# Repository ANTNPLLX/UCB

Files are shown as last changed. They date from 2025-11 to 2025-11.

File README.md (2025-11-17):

# USB Cleaner Box






**[User quick guide (EN)](Documents/user_quick_start_en.md)**

**[User quick guide (FR)](Documents/user_quick_start_fr.md)**

An interactive USB security scanning and cleaning system for Raspberry Pi with LCD display, LED indicators, button controls, and audio feedback.

Project created with the help of several LLM tools.

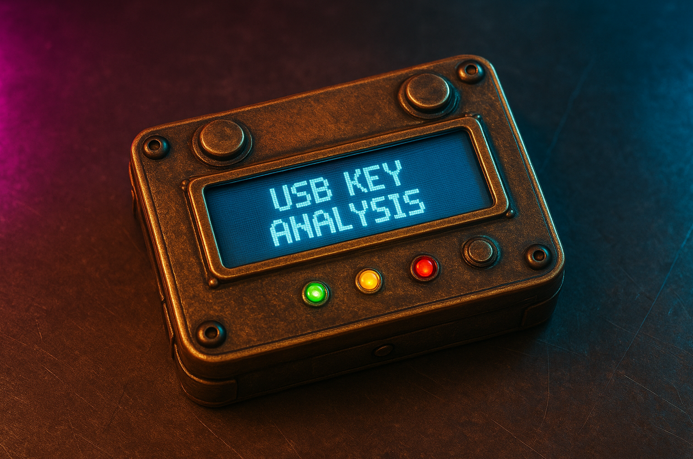
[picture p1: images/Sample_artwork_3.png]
sample_artwork


## Features

- 🔌 **Plug & Play** - Auto-detects USB devices
- 🎛️ **Interactive Interface** - Select Operation (workers) to perform on the USB Drive. 
- 📄 **Logging** - All operations logged
- 🧩 **Extensible** - Add custom workers without modifying code
  
### Built-in Workers : 
- 🔍 **Malware Scanning** - ClamAV virus detection (disabled because clamAV use too much memory for Raspberry PI 3)
- ⚡ **Executables Check** - search scripts, PE or other executable files, even if hidden.
- ❄️ **Vitrification** - Convert Office and PDF document to PDF, neutralize other files
- 🔥 **Secure Formatting** - Format USB drive in FAT32

## Quick Start

```bash
# 1. Clone or download
git clone <repository-url> UCB
cd UCB

# 2. Install dependencies
sudo apt-get update
sudo apt-get install -y python3-rpi.gpio python3-smbus clamav

# 3. Enable I2C
sudo raspi-config
# Interface Options → I2C → Enable

# 4. Make executable
chmod +x *.sh workers/*.sh

# 5. Run
sudo python3 usb_cleaner_box.py
```

## How It Works

1. **Insert USB** - Device auto-detects
2. **Answer Questions** - Use LEFT (NO) / RIGHT (YES) buttons
3. **Review Results** - LED colors show status:
   - 🟢 Green = Safe/Clean
   - 🟠 Orange = Warning/Processing
   - 🔴 Red = Threat/Error
4. **Remove USB** - When prompted "Bye bye!"

## Hardware Requirements

| Component | Specification |
|---|---|
| **Computer** | Raspberry Pi 3/4 or Zero 2 W |
| **Display** | 16x2 I2C LCD (address 0x27) |
| **LEDs** | 3x 5mm (Green, Orange, Red) |
| **Buttons** | 2x Tactile push buttons |
| **Buzzer** | Passive piezo buzzer (5V) |
| **Power** | 9V battery or USB 5V/2A |

**Total Cost**: ~$110-117 (see [Hardware Wiring Guide](Documents/HARDWARE_WIRING.md) for detailed BOM with pricing)

## Documentation

📚 **Complete documentation available in `Documents/` folder:**

| Document | Description |
|---|---|
| **[Installation Guide](Documents/INSTALLATION.md)** | Step-by-step setup instructions, dependencies, systemd service configuration |
| **[User Guide](Documents/USAGE.md)** | How to use the device with ASCII flow diagrams, button controls, and workflows |
| **[Worker Development](Documents/WORKER_GUIDE.md)** | Create custom workers with examples, templates, and best practices |
| **[Hardware Guide](Documents/HARDWARE.md)** | Component specifications, testing procedures, and hardware troubleshooting |
| **[Hardware Wiring](Documents/HARDWARE_WIRING.md)** | Complete wiring diagrams (9V battery & USB powered) with BOM and prices |
| **[FAQ](Documents/FAQ.md)** | 50+ common questions, troubleshooting tips, and detailed answers |

## Worker System

The USB Cleaner Box uses a **dynamic worker system** for extensibility:

- **Workers** are shell scripts in the `workers/` directory
- Each worker = one YES/NO question on the LCD
- Auto-discovered on startup (no code changes needed)
- Can be enabled/disabled individually
- Executed based on user choices
- Results analyzed and displayed automatically

### Built-in Workers

| Order | Question | Description | Requirements |
|---|---|---|---|
| 10 | "Full analysis?" | ClamAV malware scanning | ClamAV |
| 20 | "Executable chk?" | Detect suspicious executables | - |
| 25 | "Vitrification?" | Convert Office docs to PDF, neutralize other files | LibreOffice |
| 30 | "Format USB?" | Secure USB formatting (FAT32) | - |

### Create Custom Workers

```bash
# 1. Copy template
cp workers/TEMPLATE_worker.sh workers/my_worker.sh

# 2. Edit metadata (max 16 chars for question!)
# WORKER_QUESTION=My question?
# WORKER_ORDER=25
# WORKER_ENABLED=true

# 3. Implement logic (receives device name as $1)

# 4. Make executable
chmod +x workers/my_worker.sh

# Done! Auto-discovered on next run
```

### Enable/Disable Workers

To disable a worker without deleting it:

```bash
# Edit the worker file
nano workers/format_usb.sh

# Change WORKER_ENABLED to false
# WORKER_ENABLED=false

# Restart service
sudo systemctl restart usb-cleaner-box.service
```

Disabled workers are skipped - their questions won't appear on the LCD.

See [Worker Development Guide](Documents/WORKER_GUIDE.md) for details and examples.

## Project Structure

```
UCB/
├── usb_cleaner_box.py       # Main application
├── worker_manager.py        # Worker discovery engine
├── lcd_helper.py            # LCD controller
├── led_control.py           # LED management
├── sound_helper.py          # Buzzer/audio
├── button_input.py          # Button handling
├── usb_detection.py         # USB auto-detection
├── start.sh                 # Launcher script
├── workers/                 # Worker scripts
│   ├── analyze_malware.sh
│   ├── analyze_executables.sh
│   ├── format_usb.sh
│   └── TEMPLATE_worker.sh   # Template for new workers
├── Documents/               # Complete documentation
│   ├── INSTALLATION.md
│   ├── USAGE.md
│   ├── WORKER_GUIDE.md
│   ├── HARDWARE.md
│   ├── HARDWARE_WIRING.md
│   ├── FAQ.md
│   └── WORKER_TEMPLATE.sh
└── README.md                # This file
```

## GPIO Pin Assignments

| Component | GPIO (BCM) | Physical Pin |
|---|---|---|
| Green LED | GPIO16 | Pin 36 |
| Orange LED | GPIO20 | Pin 38 |
| Red LED | GPIO21 | Pin 40 |
| Left Button | GPIO23 | Pin 16 |
| Right Button | GPIO24 | Pin 18 |
| Buzzer | GPIO26 | Pin 37 |
| LCD Power | GPIO4 | Pin 7 |
| LCD SDA | GPIO2 | Pin 3 |
| LCD SCL | GPIO3 | Pin 5 |

## Requirements

### Software
- Raspberry Pi OS (Raspbian)
- Python 3.7+
- RPi.GPIO library
- smbus library (I2C)
- ClamAV (for malware scanning worker)
- LibreOffice (for vitrification worker - auto-installs if needed)

### Hardware
- See [Hardware Guide](Documents/HARDWARE.md) or [Hardware Wiring](Documents/HARDWARE_WIRING.md)

## Auto-Start on Boot

Install as systemd service:

```bash
# Edit service file paths
nano usb-cleaner-box.service

# Install
sudo cp usb-cleaner-box.service /etc/systemd/system/
sudo systemctl daemon-reload
sudo systemctl enable usb-cleaner-box.service
sudo systemctl start usb-cleaner-box.service

# Check status
sudo systemctl status usb-cleaner-box.service
```

## Logs

All operations are logged:

```bash
# View logs
sudo tail -f /var/log/usb_malware_scan.log
```

## Troubleshooting

### Quick Fixes

| Problem | Solution |
|---|---|
| LCD blank | Check I2C: `sudo i2cdetect -y 1` |
| USB not detected | Run with sudo |
| LEDs not working | Check polarity and resistors |
| No sound | Verify passive buzzer + transistor driver |
| ClamAV errors | Update: `sudo freshclam` |

See [FAQ](Documents/FAQ.md) for detailed troubleshooting.

## Contributing

Contributions welcome!

- **New workers** - Add functionality
- **Bug fixes** - Improve stability
- **Documentation** - Help others
- **Hardware designs** - Alternative builds
- **Translations** - Make it global

## Safety & Security

⚠️ **Important**:
- Always run with sudo (required for device access)
- Formatting **permanently deletes all data**
- Red LED = Do not use that USB drive!
- Keep virus definitions updated
- Review logs for detailed information

## License

Open source hardware and software. See individual files for specific licenses.

## Support

- 📖 Read the [Documentation](Documents/)
- 🐛 Check [FAQ](Documents/FAQ.md)
- 📝 Review [Logs](#logs)
- 💬 Open an issue (if applicable)

## Acknowledgments

- **ClamAV** - Open-source antivirus engine
- **Raspberry Pi Foundation** - Incredible platform
- **Community** - Contributors and testers

---

**Quick Links:**
- [Installation](Documents/INSTALLATION.md) | [Usage Guide](Documents/USAGE.md) | [Worker Development](Documents/WORKER_GUIDE.md) | [Hardware](Documents/HARDWARE.md) | [Hardware Wiring](Documents/HARDWARE_WIRING.md) | [FAQ](Documents/FAQ.md)

---

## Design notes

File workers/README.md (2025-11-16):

# Workers Directory

This directory contains worker scripts that perform specific tasks on USB drives. Each worker is a shell script that gets auto-discovered and executed based on user choices.

## Built-in Workers

### 1. **analyze_malware.sh** (Order: 10)
**Question:** "Analyse complete?" / "Full analysis?"
**Purpose:** Scans USB drive for malware using ClamAV antivirus engine
**Enabled:** Configurable (default: enabled)

**What it does:**
- Updates ClamAV virus signatures before scanning
- Checks internet connectivity
- Mounts USB drive and counts files
- Performs full virus scan with real-time progress
- Detects infected files and displays results
- Logs all findings to `/var/log/usb_malware_scan.log`

**Requirements:** ClamAV

**Output:**
- 🟢 Green LED: No malware detected
- 🔴 Red LED: Malware/infected files found
- 🟠 Orange LED: Scan errors or warnings

---

### 2. **analyze_executables.sh** (Order: 20)
**Question:** "Executable chk?" / "recherche fichier Executable?"
**Purpose:** Detects potentially dangerous executable files
**Enabled:** Configurable (default: enabled)

**What it does:**
- Scans for Windows executables (.exe, .dll, .bat, .msi, etc.)
- Detects Linux ELF binaries
- Finds script files (.sh, .ps1, .vbs, .js, etc.)
- Uses both file extensions and magic numbers (MZ, ELF headers)
- Displays summary and details of found executables

**Requirements:** None

**Output:**
- 🟢 Green LED: No executable files found
- 🟠 Orange LED: Suspicious executables detected

---

### 3. **file_vitrification.sh** (Order: 25)
**Question:** "Vitrification?"
**Purpose:** Converts Office documents to safe PDFs and neutralizes other files
**Enabled:** Configurable (default: enabled)

**What it does:**
- **Creates quarantine folder:** `FICHIERS_POTENTIELLEMENT_DANGEREUX/`
  - Stores all original files (not deleted!)
  - Preserves directory structure

- **Step 1A:** Vitrifies existing PDF files (removes malicious content)
  - Processes all .pdf files FIRST
  - Removes JavaScript, embedded files, forms, malicious objects
  - Output: `document.pdf` → `document.pdf_vitrified_.pdf`
  - Skips already vitrified PDFs (ending with `_vitrified_.pdf`)
  - Moves original to quarantine folder

- **Step 1B:** Converts Office documents to clean PDF files
  - Formats: .doc, .docx, .xls, .xlsx, .ppt, .pptx, .odt, .ods, .odp, .rtf
  - Output naming: `original.ext_vitrified_.pdf` (preserves original extension)
  - Removes macros and embedded scripts
  - Moves original to quarantine folder

- **Step 2:** Neutralizes other files with `.hold` extension
  - Prevents execution by renaming (e.g., `malware.exe` → `malware.exe.hold`)
  - Preserves safe formats: .txt, .jpg, .png, .mp3, .mp4, etc.

**Requirements:** LibreOffice (auto-installs if needed)

**Output:**
- 🟢 Green LED: Vitrification completed successfully
- Displays conversion and neutralization counts
- Original files preserved in quarantine folder

**Important:** Original potentially dangerous files are NOT deleted - they are moved to the `FICHIERS_POTENTIELLEMENT_DANGEREUX` folder for review

---

### 4. **format_usb.sh** (Order: 30)
**Question:** "Formatage USB?" / "Format USB?"
**Purpose:** Securely formats USB drive to FAT32
**Enabled:** Configurable (default: enabled)

**What it does:**
- **Safety checks:** Prevents formatting system/root disk
- Unmounts all partitions on the device
- Wipes partition table completely
- Creates new MBR partition table
- Creates single FAT32 partition
- Labels USB as "CLEAN_USB"
- Verifies formatting with multiple methods

**Requirements:** None

**Output:**
- 🟢 Green LED: Format successful
- 🔴 Red LED: Format failed or blocked

**⚠️ WARNING:** Formatting permanently deletes ALL data on the USB drive!

---

### 5. **secure_erase.sh** (Order: 40)
**Question:** "Effacage secure?" / "Secure erase?"
**Purpose:** Securely erases USB drive by overwriting with cryptographically random data
**Enabled:** Configurable (default: enabled)

**What it does:**
- **Maximum security:** Overwrites entire drive with random data using `/dev/urandom`
- **Safety checks:** Prevents erasing system/root disk and critical partitions
- **Progress monitoring:** Displays real-time percentage during erase operation
- Unmounts all partitions before erasing
- Calculates estimated time based on device size
- After secure erase: automatically formats to FAT32 with label "CLEAN_USB"

**Technical Details:**
- Uses `dd if=/dev/urandom of=/dev/sdX bs=4M status=progress`
- Estimated speed: ~20 MB/s write speed
- For 64GB USB: approximately 53 minutes
- Makes data forensically unrecoverable

**Requirements:** None

**Output:**
- 🟢 Green LED: Secure erase and format successful
- 🔴 Red LED: Erase failed or blocked
- LCD displays progress: "Effacement... XX%"

**⚠️ CRITICAL WARNING:**
- This operation PERMANENTLY DESTROYS all data on the USB drive
- Data cannot be recovered after secure erase
- Process can take significant time depending on drive size
- Only use when maximum security is required (e.g., sensitive data removal)

---

### 6. **report_printer.sh** (Order: 35)
**Question:** "Copie rapport?"
**Purpose:** Creates a timestamped report file on the USB drive with current session logs
**Enabled:** Configurable (default: enabled)

**Note:** This worker has Order 35 to ensure it runs BEFORE secure erase (Order 40), allowing reports to be saved before drive is wiped

**What it does:**
- Mounts USB drive
- Extracts all logs from the current session (after session banner)
- Creates timestamped report file: `YYYY-MM-DD_HH-MM_rapport_UCB.txt`
  - Example: `2025-11-15_14-30_rapport_UCB.txt`
  - Includes session banner with full device details
  - All worker choices and execution logs
  - Formatted report with headers and sections
- Displays line count and file size
- Unmounts drive after completion

**Session Detection:**
- Primary: Finds last "SESSION START" banner in logs
- Extracts everything from that banner to end of file
- Fallback: Last 30 lines if no session banner found

**Note:** Each report has a unique filename to prevent overwriting previous reports

**Requirements:** None

**Output:**
- 🟢 Green LED: Report created successfully
- 🔴 Red LED: Report creation failed
- Displays report statistics (line count)

---

### 7. **TEMPLATE_worker.sh**
**Purpose:** Template for creating new custom workers
**Enabled:** No (template only, not discovered)

This is not an active worker but a template file for developers to create new workers.

---

## Worker Metadata

Each worker contains metadata in its header:

```bash
# WORKER_QUESTION=Your question?      # Max 16 characters (displayed on LCD)
# WORKER_ORDER=100                    # Execution order (lower = earlier)
# WORKER_DESCRIPTION=Description      # Brief description
# WORKER_ENABLED=true                 # Enable/disable worker
```

---

## Enabling/Disabling Workers

To disable a worker without deleting it:

```bash
# Edit the worker file
nano workers/analyze_malware.sh

# Change WORKER_ENABLED to false
# WORKER_ENABLED=false

# Restart service
sudo systemctl restart usb-cleaner-box.service
```

Disabled workers are skipped - their questions won't appear on the LCD.

---

## Creating Custom Workers

1. **Copy the template:**
   ```bash
   cp workers/TEMPLATE_worker.sh workers/my_worker.sh
   ```

2. **Edit metadata:**
   ```bash
   # WORKER_QUESTION=My question?   # Max 16 chars!
   # WORKER_ORDER=25                # Between existing workers
   # WORKER_DESCRIPTION=What it does
   # WORKER_ENABLED=true
   ```

3. **Implement your logic:**
   - Worker receives device name as `$1` (e.g., "sdb")
   - Mount device, perform operations, unmount
   - Output keywords: `CLEAN`, `WARNING`, `INFECTED`
   - Return exit code 0 for success, non-zero for failure

4. **Make executable:**
   ```bash
   chmod +x workers/my_worker.sh
   ```

5. **Restart service:**
   ```bash
   sudo systemctl restart usb-cleaner-box.service
   ```

Worker will be auto-discovered on next run!

---

## Result Keywords

Main application analyzes worker output for keywords:

| Output Contains | Status | LED Color | Sound |
|---|---|---|---|
| `infected`, `malware`, `threat` | THREAT | 🔴 Red | Failed |
| `suspicious`, `warning:` | WARNING | 🟠 Orange | Warning |
| `clean:`, `safe`, `no` | CLEAN | 🟢 Green | Success |
| (non-zero exit code) | ERROR | 🔴 Red | Failed |

---

## Logs

All worker operations are logged to:
```
/var/log/usb_malware_scan.log
```

### Log Structure

Each session starts with a **session banner** containing:
- Timestamp
- Device path (/dev/sdX)
- Size, label, filesystem type
- Vendor, model, serial number

Example session banner:
```
================================================================================
                                 SESSION START
================================================================================
Timestamp:   2025-11-15 14:30:15
Device:      /dev/sda
Size:        58.6G
Label:       CLEAN_USB
Filesystem:  vfat
Vendor:      SanDisk
Model:       Ultra_USB_3.0
Serial:      4C530001234567890123
================================================================================
```

### Worker Choice Logging

Each worker prompt is logged:
```
[2025-11-15 14:30:20] --- "analyze_executables.sh": YES
[2025-11-15 14:30:35] --- "file_vitrification.sh": NO
[2025-11-15 14:30:40] --- "format_usb.sh": YES
```

### View Logs

View live logs:
```bash
sudo tail -f /var/log/usb_malware_scan.log
```

View last session:
```bash
sudo grep -A 999 "SESSION START" /var/log/usb_malware_scan.log | tail -100
```

---

## Worker Order

Workers are executed in order based on `WORKER_ORDER`:

1. **10** - Malware scan (detect threats first)
2. **20** - Executable check (identify suspicious files)
3. **25** - Vitrification (convert to safe formats)
4. **30** - Format (quick format - wipes partition table)
5. **35** - Report printer (copy session logs to USB)
6. **40** - Secure erase (maximum security - overwrites with random data)

You can insert custom workers between these by using intermediate order numbers (e.g., 15, 22, 28, 32, 37, 45).

---

## More Information

- **Full documentation:** [../Documents/WORKER_GUIDE.md](../Documents/WORKER_GUIDE.md)
- **Template with examples:** [TEMPLATE_worker.sh](TEMPLATE_worker.sh)
- **Main README:** [../README.md](../README.md)

---

**Made with ❤️ for USB security**

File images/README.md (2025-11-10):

## 🎨 Sample Artworks

Click any image below to view it full-size:

<p align="center">
  <a href="/images/Sample_artwork_1.png">
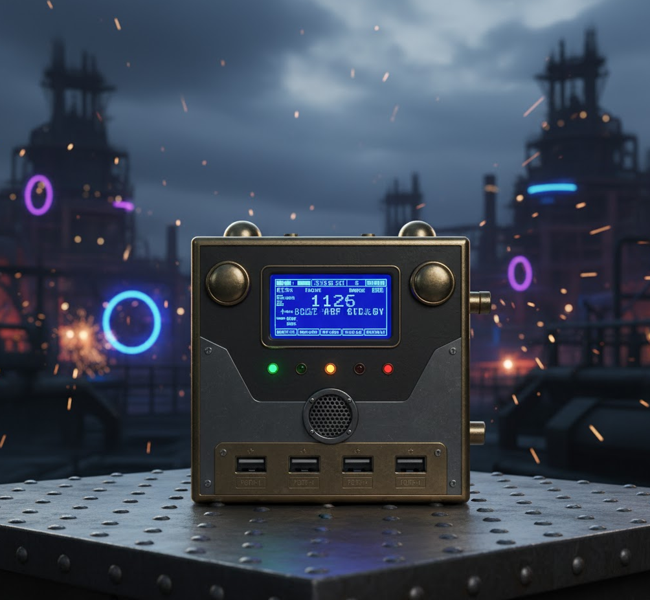
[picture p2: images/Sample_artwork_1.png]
Sample Artwork 1
    
  </a>
  <a href="/images/Sample_artwork_2.png">
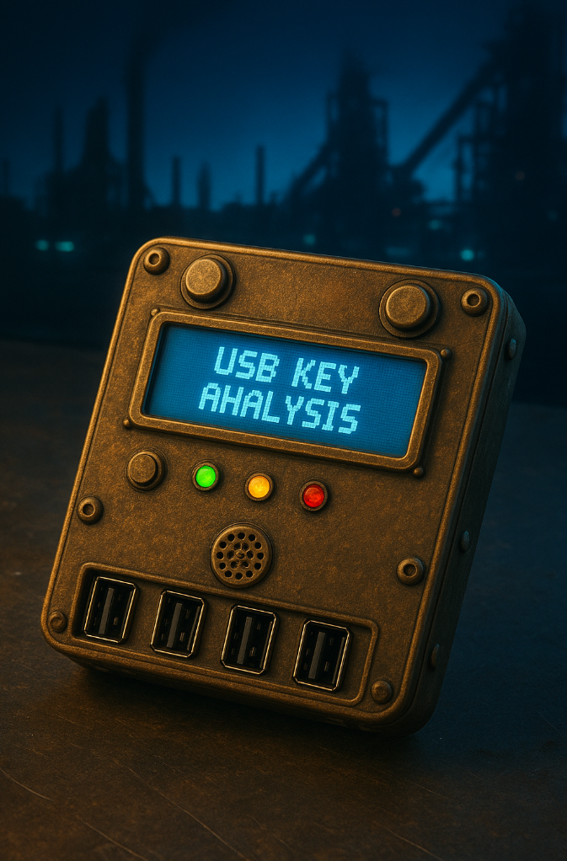
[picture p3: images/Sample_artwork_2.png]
Sample Artwork 2
    
  </a>
  <a href="/images/Sample_artwork_3.png">
    Sample Artwork 3
  </a>
  <a href="/images/Sample_artwork_4.png">
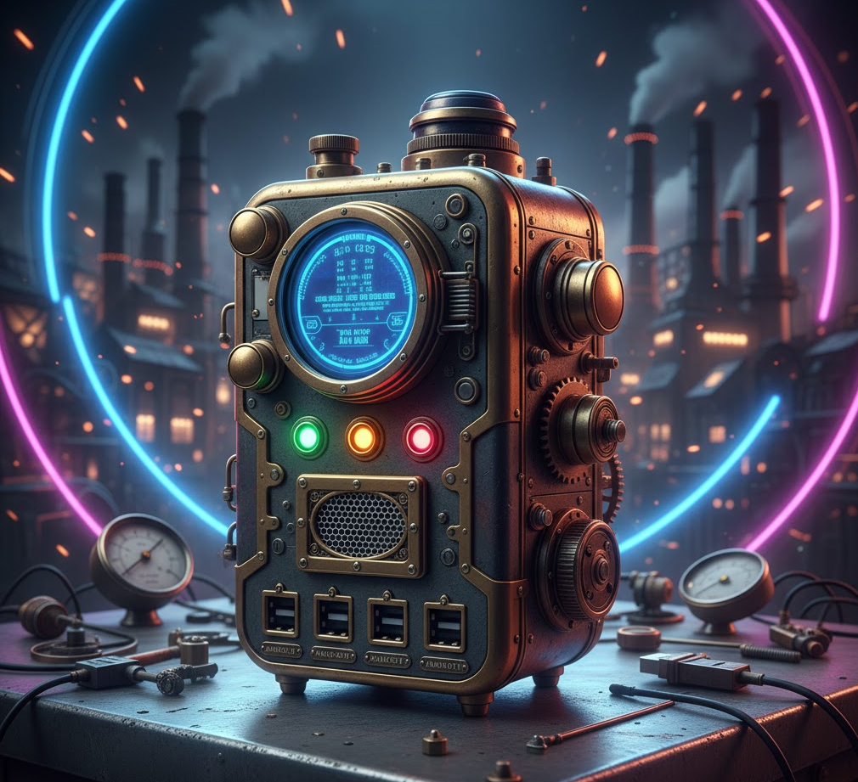
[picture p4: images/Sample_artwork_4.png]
Sample Artwork 4
    
  </a>
    <a href="/images/Sample_artwork_5.png">
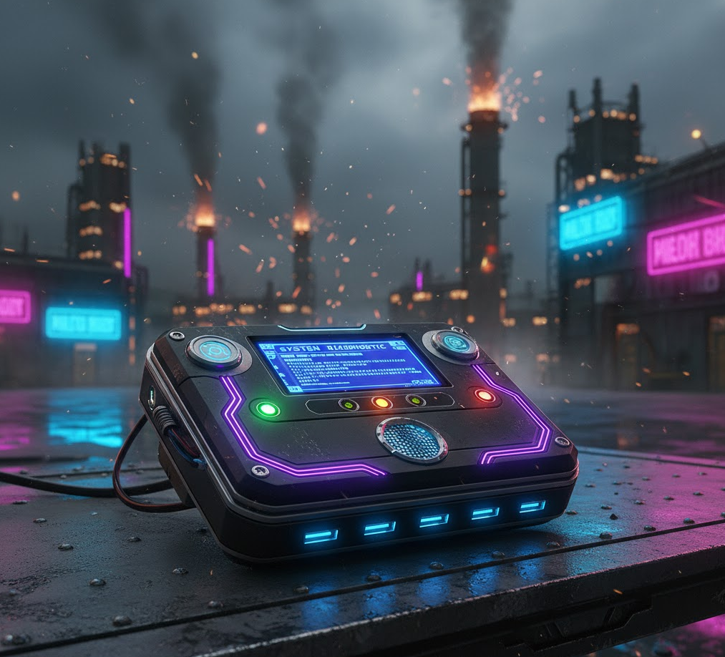
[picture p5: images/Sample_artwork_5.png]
Sample Artwork 5
    
  </a>
    <a href="/images/Sample_artwork_6.png">
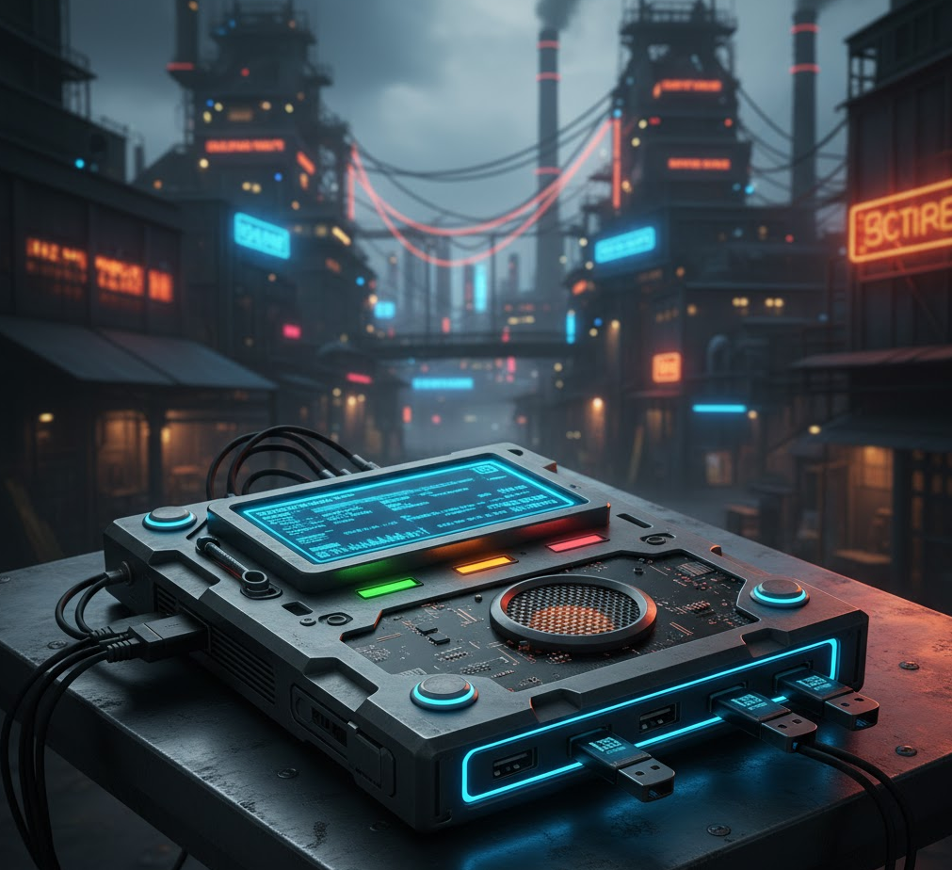
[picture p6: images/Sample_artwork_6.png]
Sample Artwork 6
    
  </a>
    <a href="/images/Sample_artwork_7.png">
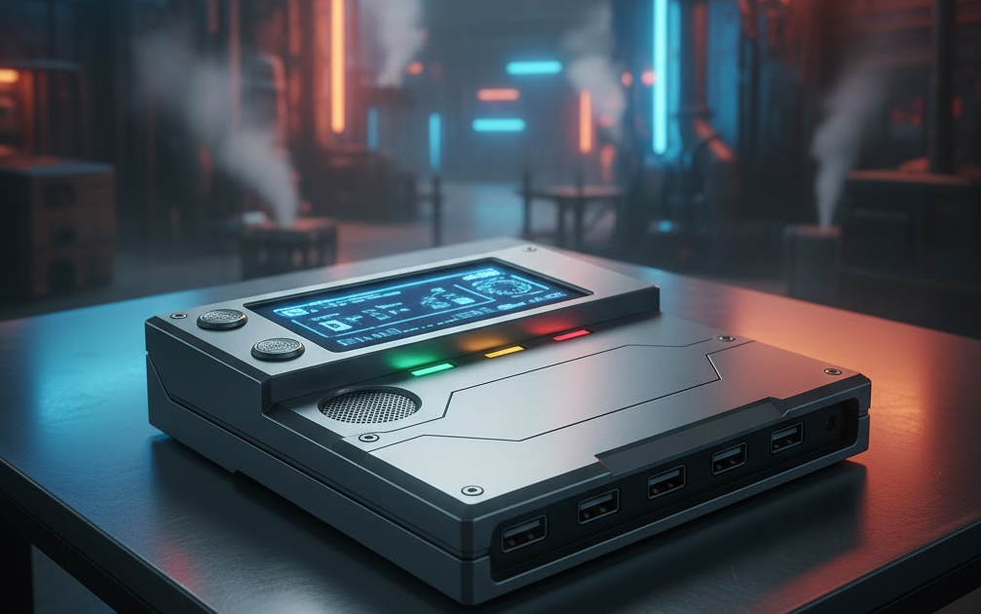
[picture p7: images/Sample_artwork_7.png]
Sample Artwork 7
    
  </a>
    <a href="/images/Sample_artwork_8.png">
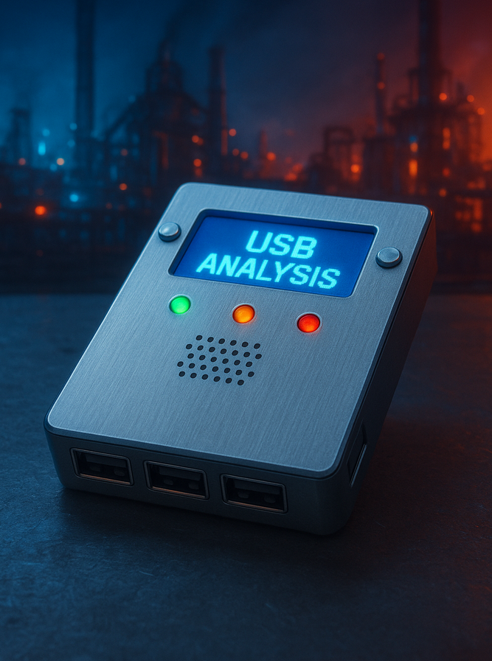
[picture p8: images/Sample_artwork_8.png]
Sample Artwork 8
    
  </a>
    <a href="/images/Sample_artwork_9.png">
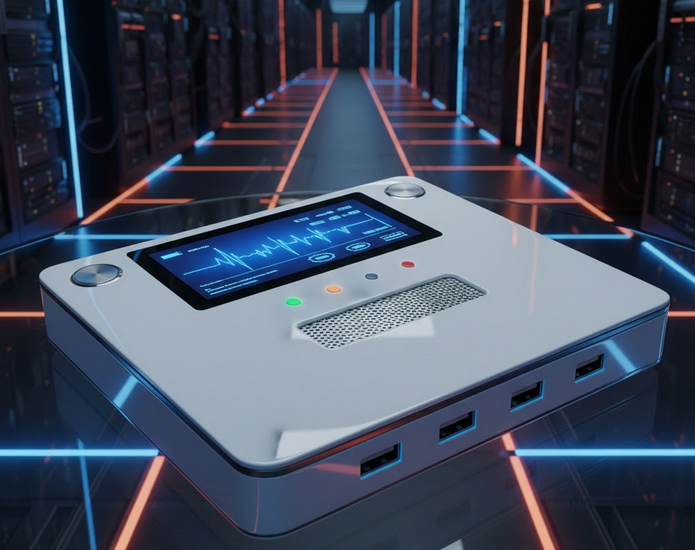
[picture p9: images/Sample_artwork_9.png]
Sample Artwork 9
    
  </a>
    <a href="/images/Sample_artwork_10.png">
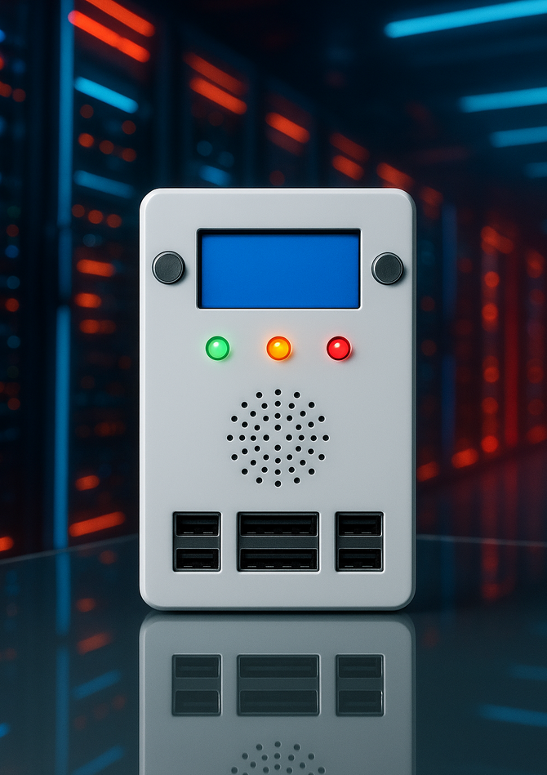
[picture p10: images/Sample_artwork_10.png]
Sample Artwork 10
    
  </a>
</p>

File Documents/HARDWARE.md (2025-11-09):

# Hardware Guide

Complete hardware documentation for building the USB Cleaner Box.

## Wiring Diagrams

Detailed wiring diagrams with two power configuration options are available in:

📁 **[Hardware Wiring Guide](HARDWARE_WIRING.md)**

This includes:
- 9V battery powered configuration
- USB powered configuration
- Complete Bill of Materials (BOM) with pricing
- GPIO pin assignments
- Assembly instructions
- Safety guidelines

---

## Quick Reference

### GPIO Pin Assignments

| Component | GPIO Pin | BCM Number | Physical Pin |
|---|---|---|---|
| Green LED | GPIO16 | 16 | Pin 36 |
| Orange LED | GPIO20 | 20 | Pin 38 |
| Red LED | GPIO21 | 21 | Pin 40 |
| Left Button (NO) | GPIO23 | 23 | Pin 16 |
| Right Button (YES) | GPIO24 | 24 | Pin 18 |
| Buzzer | GPIO26 | 26 | Pin 37 |
| LCD Power Control | GPIO4 | 4 | Pin 7 |
| LCD SDA (I2C) | GPIO2 | 2 | Pin 3 |
| LCD SCL (I2C) | GPIO3 | 3 | Pin 5 |

---

## Component Specifications

### Raspberry Pi
- **Model**: Pi 3/4 or Pi Zero 2 W
- **Power**: 5V @ 2A minimum
- **OS**: Raspberry Pi OS (Raspbian)

### LCD Display
- **Type**: 16x2 character LCD
- **Interface**: I2C
- **I2C Address**: 0x27 (default)
- **Backlight**: Controlled via I2C
- **Power Control**: GPIO4 via transistor/MOSFET

### LEDs
- **Type**: 5mm standard LEDs
- **Colors**: Green, Orange (Amber), Red
- **Forward Voltage**: ~2.0-2.2V
- **Current**: ~20mA
- **Resistors**: 220-470Ω current limiting

### Buttons
- **Type**: Tactile momentary push buttons
- **Size**: 6mm x 6mm (or larger)
- **Configuration**: Active LOW (pulled up internally)
- **Debouncing**: Handled in software

### Buzzer
- **Type**: Passive piezo buzzer
- **Voltage**: 5V
- **Driver**: NPN transistor required
- **Frequency Range**: 200Hz - 5KHz

---

## Power Requirements

### Total Power Consumption

| State | Current Draw | Power @ 5V |
|---|---|---|
| Idle (waiting) | ~150mA | ~0.75W |
| Active (scanning) | ~400-500mA | ~2.0-2.5W |
| Peak (all LEDs + sound) | ~700mA | ~3.5W |

### Recommended Power Supplies

#### Option 1: 9V Battery
- **Type**: Alkaline or NiMH rechargeable
- **Capacity**: 500-600mAh (alkaline)
- **Runtime**: 4-6 hours typical use
- **Regulator**: 5V DC-DC buck converter (recommended)
  - OR: 7805 linear regulator (less efficient)

#### Option 2: USB Power
- **Input**: 5V DC via USB connector
- **Current**: 2A minimum (2.5A recommended)
- **Source**: USB wall adapter or power bank

---

## Assembly Tips

### LED Installation

1. **Check Polarity**
   - Long leg = Anode (+)
   - Short leg = Cathode (-)
   - Flat edge = Cathode side

2. **Resistor Calculation**
   - Formula: R = (Vsupply - Vled) / Iled
   - Example: (3.3V - 2.0V) / 0.020A = 65Ω
   - Use 220Ω for safety margin

3. **Wiring**
   - Anode → Resistor → GPIO pin
   - Cathode → Ground (GND)

### Button Installation

1. **Wiring**
   - One terminal → GPIO pin
   - Other terminal → Ground (GND)
   - Internal pull-up enabled in code

2. **Debouncing**
   - Handled in software
   - No external capacitors needed

### LCD I2C Connection

1. **Connections**
   ```
   LCD VCC → 5V (via GPIO4 control)
   LCD GND → Ground
   LCD SDA → GPIO2 (Pin 3)
   LCD SCL → GPIO3 (Pin 5)
   ```

2. **Power Control Circuit**
   - GPIO4 → 1kΩ resistor → MOSFET gate
   - MOSFET source → GND
   - MOSFET drain → LCD GND
   - LCD VCC → 5V direct

### Buzzer Circuit

1. **Transistor Driver**
   ```
   GPIO26 → 1kΩ resistor → NPN base
   Buzzer (+) → 5V
   Buzzer (-) → NPN collector
   NPN emitter → GND
   Flyback diode across buzzer (cathode to 5V)
   ```

2. **Component Values**
   - Base resistor: 1kΩ
   - Transistor: 2N2222, BC547, or similar
   - Diode: 1N4148 or 1N4001

---

## Enclosure Design

### Recommended Dimensions
- **Box**: 150mm x 100mm x 50mm
- **Material**: ABS plastic or acrylic

### Cutouts Required

1. **LCD Window**
   - Size: 80mm x 36mm
   - Position: Top face, centered

2. **Buttons**
   - Size: 6mm holes
   - Position: Front face, spaced 40mm apart
   - Labels: "NO" and "YES"

3. **LEDs**
   - Size: 5mm holes
   - Position: Top face, in row
   - Spacing: 15-20mm apart
   - Order: Green, Orange, Red

4. **Power**
   - USB connector: 10mm x 6mm (side panel)
   - OR Battery compartment: Rear panel
   - Power switch: Side panel

5. **USB Port Access**
   - Cutout for Raspberry Pi USB ports
   - Position: Side panel

---

## Testing Procedures

### Pre-Power Tests

1. **Visual Inspection**
   - Check all solder joints
   - Verify no shorts between traces
   - Confirm component polarities

2. **Continuity Tests**
   - Test GND connections
   - Verify power rail continuity
   - Check GPIO connections

3. **Resistance Tests**
   - Measure LED resistor values
   - Check button pull-ups (if external)

### Power-On Tests

1. **Power Supply**
   - Measure 5V rail voltage
   - Check for voltage drops
   - Monitor current draw

2. **Component Tests**
   - LCD backlight turns on
   - LEDs light when GPIO set HIGH
   - Buttons register when pressed
   - Buzzer sounds when driven

### System Tests

1. **I2C Communication**
   ```bash
   sudo i2cdetect -y 1
   ```
   Should show address 0x27

2. **GPIO Test Script**
   Test each component individually

3. **Full Application Test**
   Run main application and verify all functions

---

## Troubleshooting Hardware

### LCD Issues

| Problem | Check | Solution |
|---|---|---|
| Blank display | Power | Verify GPIO4 is HIGH, check 5V |
| No backlight | I2C connection | Check SDA/SCL wiring |
| Random characters | I2C address | Verify address is 0x27 |
| Flickering | Poor connection | Re-solder I2C connections |

### LED Issues

| Problem | Check | Solution |
|---|---|---|
| LED doesn't light | Polarity | Swap LED connections |
| LED too dim | Resistor | Use lower value resistor |
| LED too bright | Resistor | Use higher value resistor |
| LED burns out | No resistor | Always use current-limiting resistor |

### Button Issues

| Problem | Check | Solution |
|---|---|---|
| No response | Wiring | Check GPIO and GND connections |
| Bouncing | Software | Increase debounce delay in code |
| Stuck press | Hardware | Replace button |

### Buzzer Issues

| Problem | Check | Solution |
|---|---|---|
| No sound | Driver circuit | Verify transistor connections |
| Weak sound | Power | Check 5V supply, use active buzzer |
| Continuous beep | GPIO stuck | Check software, verify transistor |

### Power Issues

| Problem | Check | Solution |
|---|---|---|
| Won't power on | Voltage | Measure 5V at Pi, check regulator |
| Random reboots | Current | Use higher-rated power supply |
| Battery drains fast | Efficiency | Use DC-DC converter instead of 7805 |

---

## Modifications & Upgrades

### Optional Enhancements

1. **Status LED**
   - Add power indicator LED
   - Use GPIO with current-limiting resistor

2. **External Antenna**
   - For better WiFi (if using wireless)
   - Connect to Pi Zero W antenna pads

3. **Cooling**
   - Add small heatsink to voltage regulator
   - Optional fan for extended use

4. **Battery Level Indicator**
   - Add voltage divider to ADC
   - Monitor battery voltage

5. **OLED Display Upgrade**
   - Replace 16x2 LCD with 128x64 OLED
   - More display options, same I2C interface

---

## Safety Considerations

### Electrical Safety

⚠️ **Warnings**:
- Never exceed 5V on GPIO pins
- Use proper current-limiting resistors
- Ensure correct polarity on all components
- Fuse the power supply (recommended)

### ESD Protection

- Use anti-static wrist strap during assembly
- Store components in anti-static bags
- Avoid touching component pins

### Thermal Safety

- Ensure adequate ventilation
- Don't block airflow around Pi
- Add heatsink to voltage regulator if warm
- Monitor temperatures during extended use

---

## Maintenance

### Regular Checks

- Inspect solder joints for cracks
- Clean dust from enclosure
- Check battery voltage (if battery powered)
- Tighten loose connections
- Verify all LEDs working

### Cleaning

- Power off before cleaning
- Use dry cloth for exterior
- Compressed air for dust removal
- Avoid liquid cleaners near electronics

---

## Resources

### Datasheets
- [Raspberry Pi GPIO](https://pinout.xyz/)
- [16x2 LCD I2C Module](https://www.handsontec.com/dataspecs/module/I2C_1602_LCD.pdf)
- [2N2222 Transistor](https://www.onsemi.com/pdf/datasheet/p2n2222a-d.pdf)

### Tools
- [Fritzing](https://fritzing.org/) - Circuit design software
- [GPIO Reference](https://pinout.xyz/) - Pin reference

### Calculators
- [LED Resistor Calculator](https://www.digikey.com/en/resources/conversion-calculators/conversion-calculator-led-series-resistor)
- [Ohm's Law Calculator](https://www.calculator.net/ohms-law-calculator.html)

---

For complete wiring diagrams with BOM and pricing, see **[Hardware Wiring Guide](HARDWARE_WIRING.md)**.

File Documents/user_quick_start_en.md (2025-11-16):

# USB Cleaning Box - User Guide

## Step 1: Starting the Device
1. **Connect the power supply** - Plug the power cable into the device
2. **Wait for initialization** - Please wait approximately 20 seconds
3. **Device ready** - The screen displays: "Inserer une / clé USB..."

## Step 2: Insert the USB Drive
- Insert the USB drive into the USB port of the device

## Step 3: Choose the Treatments
For each available treatment, the screen displays a question
- **LEFT BUTTON (NO)** - Skip to the next treatment
- **RIGHT BUTTON (YES)** - Start the treatment

---

### Treatment Explanations
## "Executable chk?"
Detects potentially dangerous files (Windows .exe programs, scripts, Linux binaries).

## "Vitrification?"
Converts Office documents and PDFs into cleaned PDF files (removes macros, JavaScript, malicious objects). Original files are moved to the "FICHIERS_POTENTIELLEMENT_DANGEREUX" folder.

**Results:**
- Cleaned files: renamed to `filename.ext_vitrified_.pdf`
- Original files: moved to `FICHIERS_POTENTIELLEMENT_DANGEREUX/`
- Other files: renamed with `.hold` extension

## "Formatage USB?"
Erases ALL data and formats the USB drive to FAT32 (label "CLEAN_USB").

**⚠️ WARNING: This operation PERMANENTLY DELETES all data!**

## "Effacage secure?"
Securely erases the USB drive by overwriting ALL data with random data with this command 'dd if=/dev/urandom of="$DEVICE_PATH" bs=4M'.
This operation makes the data nearly impossible to recover.
Duration: approximately 50 minutes for a 64 GB drive

**⚠️ CRITICAL WARNING:**
- This operation PERMANENTLY DESTROYS all data

## "Copie rapport?"
Creates a report file on the USB drive with all logs from the current session: detailed information about the USB drive, treatments performed, analysis results, detected or processed files.

**File created:** `YYYY-MM-DD_HH-MM_rapport_UCB.txt`

## "Recommencer?"
After all treatments, the device offers to start over:
- **YES** - Restart the questions for the same USB drive
- **NO** - Proceed to the end message

---

### Step 4: Remove the Drive
- When the screen displays "Au revoir / Retirer cle USB"
- Remove the USB drive from the device
- The device is ready for a new drive

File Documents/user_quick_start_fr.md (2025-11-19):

# Boîtier Nettoyage USB - Guide utilisateur

## Étape 1 : Démarrage du boîtier
1. **Brancher l'alimentation** - Connectez le câble d'alimentation au boîtier
2. **Attendre l'initialisation** - Patienter environ 20 secondes
3. **Boitier prêt** - L'écran affiche : "Inserer une / clé USB..."

## Étape 2 : Insérer la Clé USB
- Insérer la clé USB dans le port USB du boîtier

## Étape 3 : Choisir les Traitements
Pour chaque traitement disponible, l'écran affiche une question
- **Bouton GAUCHE (NON)** - Passer au traitement suivant
- **Bouton DROIT (OUI)** - Lancer le traitement

---

### Explications des traitements

| Command | Description | Mise en garde |
| --- | --- | --- |
| Executable chk? | Détecte les fichiers potentiellement dangereux (programmes Windows .exe, scripts, binaires Linux). |
| Vitrification? | Convertit les documents Office et PDF en fichiers PDF nettoyés (supprime macros, JavaScript, objets malveillants). | Fichiers nettoyés : renommés en `nom_fichier.ext_vitrified_.pdf`. Fichiers originaux : déplacés dans `FICHIERS_POTENTIELLEMENT_DANGEREUX/`, Autres fichiers : renommés avec extension `.hold` |
| Formatage USB? | Formatage rapide de la clé USB en FAT32 (nom "CLEAN_USB"). | suppression de tous les fichiers 
| Effacage secure? | Efface les données de la clé USB en écrasant TOUTES les données avec des données aléatoires avec la commande 'dd if=/dev/urandom of="$DEVICE_PATH" bs=4M'. Durée : environ 10 minutes pour une clé de 4 Go | Cette opération rend les données presque impossibles à récupérer.
| Copie rapport?" | Crée un fichier rapport sur la clé USB avec tous les logs de la session en cours : informations détaillées sur la clé USB, traitements effectués, résultats des analyses, fichiers détectés ou traités.| Fichier créé à la racine de la clé : `YYYY-MM-DD_HH-MM_rapport_UCB.txt`|

---

### Étape 4 : Retirer la Clé
- Lorsque l'écran affiche "Au revoir / Retirer cle USB"
- Retirer la clé USB du boîtier
- Le boîtier est prêt pour une nouvelle clé

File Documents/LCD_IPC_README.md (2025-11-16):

# LCD IPC System - Worker to Main App Communication

## Overview

The USB Cleaner Box uses an Inter-Process Communication (IPC) mechanism to allow worker bash scripts to update the LCD display. This is necessary because workers run as separate processes and cannot directly call Python methods.

## Architecture

```
┌─────────────────┐
│ Worker Script   │
│ (bash)          │
└────────┬────────┘
         │
         │ display_on_lcd "Line 1" "Line 2"
         │
         ▼
┌─────────────────┐
│ lcd_helper.sh   │  (sources into worker)
└────────┬────────┘
         │
         │ Calls python3 lcd_ipc.py
         │
         ▼
┌─────────────────┐
│ lcd_ipc.py      │  (writes to /tmp/ucb_lcd_command)
└────────┬────────┘
         │
         │ JSON: {"line1": "...", "line2": "..."}
         │
         ▼
┌─────────────────┐
│ /tmp/           │
│ ucb_lcd_command │  (temp file)
└────────┬────────┘
         │
         │ Monitor thread checks every 100ms
         │
         ▼
┌─────────────────┐
│ LCDIPCMonitor   │  (background thread in main app)
│ (Python)        │
└────────┬────────┘
         │
         │ Reads file, parses JSON
         │
         ▼
┌─────────────────┐
│ LCD.display()   │  (actual hardware update)
│ (Python)        │
└─────────────────┘
```

## Components

### 1. `lcd_ipc.py`
Python module providing:
- **`LCDIPCMonitor`**: Background thread that monitors `/tmp/ucb_lcd_command`
- **`send_lcd_command()`**: Helper function to send LCD commands

### 2. `workers/lcd_helper.sh`
Bash helper script that workers source. Provides:
- **`display_on_lcd(line1, line2)`**: Function callable from bash

### 3. `/tmp/ucb_lcd_command`
Temporary file used for IPC:
- Written by workers via `lcd_ipc.py`
- Read by `LCDIPCMonitor` thread
- JSON format: `{"line1": "text", "line2": "text"}`

## Usage in Workers

All worker scripts automatically have access to `display_on_lcd()`:

```bash
#!/bin/bash

# Configuration
SCAN_LOG="/var/log/usb_malware_scan.log"

# Get script directory
SCRIPT_DIR="$(cd "$(dirname "${BASH_SOURCE[0]}")" && pwd)"

# Source LCD helper for display_on_lcd function
source "${SCRIPT_DIR}/lcd_helper.sh"

# Now you can use display_on_lcd anywhere in the script
display_on_lcd "Scanning..." "Please wait"

# Do some work...

display_on_lcd "Scan complete" "Found: 0 files"
```

## Timing and Synchronization

- **Write latency**: ~10ms (file write + flush)
- **Monitor polling**: 100ms interval
- **Update latency**: Typically 10-200ms
- **Non-blocking**: Workers don't wait for LCD update

This means LCD updates appear nearly instantly but don't slow down worker execution.

## Error Handling

All IPC operations are designed to fail silently:
- If LCD monitor is not running, commands are ignored
- If file write fails, worker continues normally
- No error messages are shown to avoid disrupting operation

## Testing

### Test from Python:
```python
from lcd_ipc import send_lcd_command
send_lcd_command("Python Test", "Line 2")
```

### Test from Bash:
```bash
source /home/antoine/raspberry/UCB/workers/lcd_helper.sh
display_on_lcd "Bash Test" "Line 2"
```

### Verify command file:
```bash
cat /tmp/ucb_lcd_command
# Should show: {"line1": "...", "line2": "..."}
```

## Lifecycle

1. **Startup**: Main app starts `LCDIPCMonitor` thread
2. **Worker execution**: Workers call `display_on_lcd()`
3. **Update**: Monitor detects file change and updates LCD
4. **Cleanup**: Monitor thread stops on app shutdown

## Performance

- **Memory**: Minimal (~1KB for JSON command)
- **CPU**: Negligible (100ms polling interval)
- **Disk I/O**: Minimal (small file writes to /tmp - RAM-based)

## Alternatives Considered

1. **Named pipes (FIFO)**: More complex, blocking behavior
2. **Unix sockets**: Requires connection management
3. **Shared memory**: Platform-specific, complex
4. **File-based IPC**: ✅ Simple, reliable, portable

## Troubleshooting

### LCD not updating from workers:

1. Check monitor is running:
   ```bash
   ps aux | grep lcd_ipc
   ```

2. Check command file exists after worker call:
   ```bash
   ls -l /tmp/ucb_lcd_command
   cat /tmp/ucb_lcd_command
   ```

3. Test manually:
   ```bash
   python3 /home/antoine/raspberry/UCB/lcd_ipc.py "Test 1" "Test 2"
   ```

4. Check main app logs for errors

### Stale LCD display:

- Monitor only updates on file modification
- Touch the file to force update:
  ```bash
  touch /tmp/ucb_lcd_command
  ```

## Future Enhancements

Possible improvements:
- Add command queue for multiple rapid updates
- Support for LCD clear, backlight control
- Bidirectional communication (responses to workers)
- Multiple worker coordination

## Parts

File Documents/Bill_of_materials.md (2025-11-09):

# USB Cleaner Box - Bill of materials 

This directory contains the list of material needed for building the USB Cleaner Box hardware.

## Bill of Materials (BOM)

### Core Components

| Qty | Component | Description | Notes | Avg Price |
|-----|---|---|---|---|
| 1 | Raspberry Pi 3 | Main microcontroller | Or Pi Zero 2 W for better performance | 47.00€ |
| 1 | 16x2 I2C LCD Display | Character display, I2C interface | I2C address: 0x27 | 9.00€ |
| 3 | 5mm LEDs | Status indicators | 1x Green, 1x Orange, 1x Red | 0.10€ |
| 3 | 220Ω Resistors | LED current limiting | 1/4W or 1/8W | 0.05€ |
| 2 | Metal Push Buttons | User input (YES/NO) | 12mm x 12mm momentary switches | 3.00€ |
| 1 | Passive Buzzer | Audio feedback | 5V, 12mm diameter | 0.50€ |

**Core Components Subtotal: 62.95€**

### Power Supply Components

#### For 9V Battery Configuration:
| Qty | Component | Description | Notes | Avg Price |
|-----|---|---|---|---|
| 1 | 9V Battery Connector | Battery snap connector | With leads | 0.50€ |
| 1 | 9V Battery | Power source | Alkaline or rechargeable NiMH | 3.00€ |
| 1 | 5V Voltage Regulator | Step-down converter |  DC-DC buck converter (more efficient) | 1.50€ |
| 1 | Metal Power Switch | On/Off control | SPST toggle or slide switch | 4.00€ |

**9V Battery Configuration Subtotal: 9.00€**

#### For USB Powered Configuration:
| Qty | Component | Description | Notes | Avg Price |
|-----|---|---|---|---|
| 1 | USB Connector | Power input | Micro USB or Mini USB | 1.50€ |
| 1 | USB Power Cable | 5V power supply | 5V/2A wall adapter recommended | 10.00€ |
| 1 | Power Switch | On/Off control (optional) | SPST toggle or slide switch | 4.00€ |

**USB Configuration Subtotal: 15.50€**

### Enclosure & Mounting

| Qty | Component | Description | Notes | Avg Price |
|-----|---|---|---|---|
| 1 | Project Box | Enclosure | Recommended: 150x100x50mm | 30.00€ |
| 4 | M2.5 Screws | Pi mounting | 10mm length | 0.50€ |
| 4 | M2.5 Standoffs | Pi standoffs | 10mm height | 0.40€ |
| 1 | Prototype PCB or Breadboard | Component mounting | Optional, for permanent build | 3.00€ |
| 1 | Jumper Wires Set | Connections | Male-to-female, various lengths | 5.00€ |

**Enclosure & Mounting Subtotal: 38.9€**

---

## Total Cost Summary

### 9V Battery Powered Configuration:
- Core Components: **62.95€**
- Power Supply (9V): **9.00€**
- Enclosure & Mounting: **38.9€**

**Total: ~110.85€** (excluding tools)

### USB Powered Configuration:
- Core Components: **62.95€**
- Power Supply (USB): **15.50€**
- Enclosure & Mounting: **38.9€**

**Total: ~117.35€** (excluding tools)

> *Prices are approximate averages in Euros and may vary by supplier, location, and time. Bulk purchases or existing component inventory can reduce costs significantly.*

---

## License

Hardware designs are open source. Feel free to modify and adapt for your needs.

## Contributing

Found an issue or have an improvement? Please open an issue or submit a pull request!

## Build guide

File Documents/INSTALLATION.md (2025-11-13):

# Installation Guide

Complete installation instructions for the USB Cleaner Box application.

## Prerequisites

### Hardware Requirements
- Raspberry Pi (Pi 3/4 or Pi Zero 2 W recommended)
- 16x2 I2C LCD display (I2C address: 0x27)
- 3 LEDs (Green, Orange, Red)
- 2 Push buttons
- Passive buzzer
- Power supply (9V battery or USB)

See [Hardware Wiring Guide](HARDWARE_WIRING.md) for complete wiring diagrams.

### System Requirements
- Raspberry Pi OS (Raspbian)
- Python 3.7 or higher
- Internet connection (for initial setup)

---

## Installation Steps

### 1. System Update

```bash
sudo apt-get update
sudo apt-get upgrade -y
```

### 2. Install Python Dependencies

```bash
sudo apt-get install -y python3-rpi.gpio python3-smbus python3-pip
```

### 3. Install ClamAV (Antivirus)

For malware scanning functionality:

```bash
sudo apt-get install -y clamav clamav-daemon
```

Update virus definitions (this may take 10-15 minutes):

```bash
sudo systemctl stop clamav-freshclam
sudo freshclam
sudo systemctl start clamav-freshclam
```

### 4. Install LibreOffice (Optional)

For file vitrification worker (converts Office documents to PDF):

```bash
sudo apt-get install -y libreoffice-writer libreoffice-calc libreoffice-core fonts-liberation fonts-dejavu-core
```

**Note:** The vitrification worker will auto-install LibreOffice and fonts on first run if not present. Manual installation is recommended to avoid delays during USB processing.

### 5. Enable I2C Interface

The LCD uses I2C communication:

```bash
sudo raspi-config
```

Navigate to:
- **Interface Options** → **I2C** → **Enable**

Reboot if prompted:

```bash
sudo reboot
```

### 6. Verify I2C LCD

Check that the LCD is detected:

```bash
sudo i2cdetect -y 1
```

You should see `27` in the output grid (I2C address 0x27).

### 7. Download/Clone the Application

```bash
cd ~
git clone <repository-url> UCB
cd UCB
```

Or if you have the files:

```bash
cd /path/to/UCB
```

### 8. Make Scripts Executable

```bash
chmod +x *.sh
chmod +x *.py
chmod +x workers/*.sh
```

### 9. Test the Application

Run a quick test:

```bash
sudo python3 usb_cleaner_box.py
```

You should see:
- LCD turns on with "USB drive / Cleaner Box"
- LED snake animation
- Startup jingle plays

Press `Ctrl+C` to stop.

---

## Optional: Auto-Start on Boot

### Method 1: Using systemd Service

1. **Edit the service file** to match your installation path:

```bash
nano usb-cleaner-box.service
```

Update these lines:
```
WorkingDirectory=/home/pi/UCB
ExecStart=/usr/bin/python3 /home/pi/UCB/usb_cleaner_box.py
```

2. **Install the service**:

```bash
sudo cp usb-cleaner-box.service /etc/systemd/system/
sudo systemctl daemon-reload
sudo systemctl enable usb-cleaner-box.service
```

3. **Start the service**:

```bash
sudo systemctl start usb-cleaner-box.service
```

4. **Check status**:

```bash
sudo systemctl status usb-cleaner-box.service
```

5. **View logs**:

```bash
sudo journalctl -u usb-cleaner-box.service -f
```

### Method 2: Using rc.local

Add to `/etc/rc.local` before `exit 0`:

```bash
sudo nano /etc/rc.local
```

Add:
```bash
cd /home/pi/UCB && sudo python3 usb_cleaner_box.py &
```

---

## Configuration

### Customizing Workers

Workers are automatically discovered from the `workers/` directory. See [Worker Development Guide](WORKER_GUIDE.md) for creating custom workers.

To enable or disable workers, edit the `WORKER_ENABLED` line in each worker file:

```bash
# Disable a worker
nano workers/format_usb.sh
# Change: WORKER_ENABLED=false

# Restart service
sudo systemctl restart usb-cleaner-box.service
```

### LCD I2C Address

If your LCD uses a different I2C address, edit `lcd_helper.py`:

```python
I2C_ADDR = 0x27  # Change to your LCD address
```

### GPIO Pin Configuration

Default GPIO pin assignments in the code:

| Component | GPIO Pin |
|---|---|
| Green LED | GPIO16 |
| Orange LED | GPIO20 |
| Red LED | GPIO21 |
| Left Button | GPIO23 |
| Right Button | GPIO24 |
| Buzzer | GPIO26 |
| LCD Power | GPIO4 |

To change pins, edit the respective Python modules.

---

## Troubleshooting

### LCD Not Displaying

**Problem**: LCD is blank or shows random characters

**Solutions**:
1. Check I2C connection:
   ```bash
   sudo i2cdetect -y 1
   ```
2. Verify GPIO4 is powering the LCD
3. Check LCD I2C address in code
4. Verify I2C is enabled in `raspi-config`

### LEDs Not Working

**Problem**: LEDs don't light up

**Solutions**:
1. Check LED polarity (long leg = positive)
2. Verify resistor values (220Ω recommended)
3. Test LEDs separately with simple script
4. Check GPIO pin connections

### Buttons Not Responding

**Problem**: Buttons don't trigger actions

**Solutions**:
1. Verify button connections (one side to GPIO, other to GND)
2. Check pull-up resistors are configured (internal or external)
3. Test buttons with simple script
4. Ensure buttons are momentary, not latching

### No Sound from Buzzer

**Problem**: Buzzer is silent

**Solutions**:
1. Verify buzzer is passive (not active)
2. Check transistor driver circuit
3. Test buzzer separately at 5V
4. Verify GPIO26 connection

### USB Not Detected

**Problem**: Application doesn't detect plugged USB

**Solutions**:
1. Check USB device appears in `lsblk`
2. Run with sudo (required for device access)
3. Check debug output in terminal
4. Verify USB is not auto-mounting elsewhere

### ClamAV Errors

**Problem**: Malware scanning fails

**Solutions**:
1. Update virus definitions:
   ```bash
   sudo freshclam
   ```
2. Check ClamAV is installed:
   ```bash
   clamscan --version
   ```
3. Verify worker script permissions
4. Check system has enough RAM (1GB+ recommended)

### Permission Errors

**Problem**: "Permission denied" errors

**Solutions**:
1. Run with sudo:
   ```bash
   sudo python3 usb_cleaner_box.py
   ```
2. Check script permissions:
   ```bash
   ls -l workers/
   ```
3. Make scripts executable:
   ```bash
   chmod +x workers/*.sh
   ```

---

## Updating

### Update Application Code

```bash
cd ~/UCB
git pull
chmod +x *.sh workers/*.sh
```

### Update ClamAV Definitions

```bash
sudo freshclam
```

### Update System

```bash
sudo apt-get update
sudo apt-get upgrade
```

---

## Uninstallation

### Stop and Disable Service

```bash
sudo systemctl stop usb-cleaner-box.service
sudo systemctl disable usb-cleaner-box.service
sudo rm /etc/systemd/system/usb-cleaner-box.service
sudo systemctl daemon-reload
```

### Remove Application

```bash
rm -rf ~/UCB
```

### Remove Dependencies (Optional)

```bash
sudo apt-get remove clamav clamav-daemon
sudo apt-get autoremove
```

---

## Next Steps

- **Usage**: See [Usage Guide](USAGE.md)
- **Worker Development**: See [Worker Guide](WORKER_GUIDE.md)
- **Hardware**: See [Hardware Guide](HARDWARE.md)
- **Hardware Wiring**: See [Hardware Wiring](HARDWARE_WIRING.md)
- **Troubleshooting**: See [FAQ](FAQ.md)

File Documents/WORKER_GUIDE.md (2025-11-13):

# Worker Development Guide

Complete guide for creating custom workers for the USB Cleaner Box.

## Quick Start

1. Copy the template: `cp workers/TEMPLATE_worker.sh workers/my_worker.sh`
2. Edit metadata (must be max 16 chars for question!)
3. Implement your logic
4. Make executable: `chmod +x workers/my_worker.sh`
5. Done! It will auto-appear on next run

See [WORKER_TEMPLATE.sh](WORKER_TEMPLATE.sh) for the complete template with detailed comments.

---

## Worker Metadata

Each worker must include metadata in header comments:

```bash
# WORKER_QUESTION=Your question?
# WORKER_ORDER=100
# WORKER_DESCRIPTION=Description of what this worker does
# WORKER_ENABLED=true
```

### Fields

| Field | Required | Description | Example |
|---|---|---|---|
| `WORKER_QUESTION` | **YES** | Question on LCD (max 16 chars) | `Backup files?` |
| `WORKER_ORDER` | No | Execution order (default: 999) | `25` |
| `WORKER_DESCRIPTION` | No | Brief description | `Backup important files` |
| `WORKER_ENABLED` | No | Enable/disable worker (default: true) | `true` or `false` |

**Important**: Workers without `WORKER_QUESTION` are ignored!

---

## Worker Order

Built-in workers:
- **10** - analyze_malware.sh
- **20** - analyze_executables.sh  
- **30** - format_usb.sh

Use numbers in between or higher for your custom workers.

---

## Worker Interface

### Input

Workers receive the USB device name as first parameter:

```bash
DEVICE=$1          # e.g., "sdb"
DEVICE_PATH="/dev/$DEVICE"  # e.g., "/dev/sdb"
```

### Output

Print status messages to stdout:

```bash
echo "Scanning files..."
echo "CLEAN: No threats found"
echo "WARNING: Suspicious files detected"
echo "INFECTED: Malware found!"
```

### Exit Codes

Return appropriate codes:

```bash
exit 0   # Success
exit 1   # Error/Failure
```

---

## Result Analysis

Main application analyzes output for keywords:

| Output Contains | Status | LED | Sound |
|---|---|-----|---|
| "infected", "malware", "threat" | THREAT | Red | Failed |
| "suspicious", "warning" | WARNING | Orange | Warning |
| "clean", "safe", "no" | CLEAN | Green | Success |
| (non-zero exit) | ERROR | Red | Failed |

---

## Enabling/Disabling Workers

Workers can be enabled or disabled without deleting them.

### How It Works

- **Enabled workers** (`WORKER_ENABLED=true`): Questions appear on LCD
- **Disabled workers** (`WORKER_ENABLED=false`): Skipped entirely, no LCD prompt

### Use Cases

- **Testing**: Disable workers while developing new ones
- **Maintenance**: Temporarily disable problematic workers
- **Customization**: Only run the workers you need

### How to Disable a Worker

1. **Edit the worker file:**
   ```bash
   nano workers/format_usb.sh
   ```

2. **Change the WORKER_ENABLED line:**
   ```bash
   # From:
   # WORKER_ENABLED=true

   # To:
   # WORKER_ENABLED=false
   ```

3. **Restart the application:**
   ```bash
   sudo systemctl restart usb-cleaner-box.service
   ```

### How to Re-Enable a Worker

1. Change `WORKER_ENABLED=false` back to `WORKER_ENABLED=true`
2. Restart the service

### Example: Disable Format Worker

```bash
# Edit the format worker
sudo nano /home/pi/UCB/workers/format_usb.sh

# Change line 8 to:
# WORKER_ENABLED=false

# Save and restart
sudo systemctl restart usb-cleaner-box.service
```

Now the "Format USB?" question will not appear on the LCD.

### Accepted Values

The following values are recognized (case-insensitive):

| Value | Result |
|---|---|
| `true`, `yes`, `1` | Worker enabled |
| `false`, `no`, `0` | Worker disabled |
| (omitted) | Defaults to `true` (enabled) |

---

## Example Workers

### 1. Count Files

```bash
#!/bin/bash
# WORKER_QUESTION=Count files?
# WORKER_ORDER=15
# WORKER_DESCRIPTION=Count total files on USB
# WORKER_ENABLED=true

DEVICE=$1
MOUNT_POINT="/media/count_$DEVICE"

sudo mkdir -p "$MOUNT_POINT"
sudo mount "/dev/${DEVICE}1" "$MOUNT_POINT"

COUNT=$(find "$MOUNT_POINT" -type f | wc -l)
echo "CLEAN: Found $COUNT files"

sudo umount "$MOUNT_POINT"
sudo rmdir "$MOUNT_POINT"
exit 0
```

### 2. Find Large Files

```bash
#!/bin/bash
# WORKER_QUESTION=Find big files?
# WORKER_ORDER=40
# WORKER_DESCRIPTION=Find files > 100MB
# WORKER_ENABLED=true

DEVICE=$1
MOUNT_POINT="/media/large_$DEVICE"

sudo mkdir -p "$MOUNT_POINT"
sudo mount "/dev/${DEVICE}1" "$MOUNT_POINT"

echo "Searching for files > 100MB..."
LARGE=$(find "$MOUNT_POINT" -type f -size +100M)

if [ -z "$LARGE" ]; then
    echo "CLEAN: No large files found"
else
    echo "WARNING: Large files detected"
    echo "$LARGE"
fi

sudo umount "$MOUNT_POINT"
sudo rmdir "$MOUNT_POINT"
exit 0
```

### 3. File Vitrification (Office to PDF)

```bash
#!/bin/bash
# WORKER_QUESTION=Vitrification?
# WORKER_ORDER=25
# WORKER_DESCRIPTION=Convert Office docs to PDF, neutralize other files
# WORKER_ENABLED=true

DEVICE=$1
MOUNT_POINT="/media/vitrify_$DEVICE"

# Check if LibreOffice is installed
if ! command -v libreoffice &> /dev/null; then
    echo "Installing LibreOffice..."
    sudo apt-get update -qq
    sudo apt-get install -y libreoffice --no-install-recommends
fi

sudo mkdir -p "$MOUNT_POINT"
sudo mount "/dev/${DEVICE}1" "$MOUNT_POINT"

# Convert Office documents to PDF
CONVERTED=0
for file in $(sudo find "$MOUNT_POINT" -type f -iname "*.doc*" -o -iname "*.xls*" -o -iname "*.ppt*"); do
    dirname=$(dirname "$file")
    if sudo -u pi libreoffice --headless --convert-to pdf --outdir "$dirname" "$file" 2>&1; then
        sudo rm "$file"
        CONVERTED=$((CONVERTED + 1))
    fi
done

# Neutralize other files with .hold extension
NEUTRALIZED=0
for file in $(sudo find "$MOUNT_POINT" -type f ! -iname "*.pdf" ! -iname "*.txt" ! -iname "*.jpg"); do
    sudo mv "$file" "${file}.hold"
    NEUTRALIZED=$((NEUTRALIZED + 1))
done

echo "CLEAN: Converted $CONVERTED docs, neutralized $NEUTRALIZED files"

sudo umount "$MOUNT_POINT"
sudo rmdir "$MOUNT_POINT"
exit 0
```

**Note:** Requires LibreOffice. Auto-installs on first run if not present.

---

## Best Practices

### Questions
- Keep under 16 characters
- Be clear and concise
- Use "?" at the end
- Use abbreviations: "Executable chk?" not "Check Executables?"

### Output
- Print progress for long operations
- Use keywords: CLEAN, WARNING, INFECTED
- Be informative in messages
- Log to `/var/log/usb_malware_scan.log`

### Error Handling
- Check if device exists
- Verify mount successful
- Handle timeouts gracefully
- Clean up on errors

### Cleanup
- Always unmount devices
- Remove temporary files
- Free resources

---

## Restrictions

### Don't Do This
- ❌ Access GPIO pins (conflicts with main app)
- ❌ Write to I2C bus (used by LCD)
- ❌ Use `display_on_lcd()` function (disabled)
- ❌ Modify system audio settings
- ❌ Run indefinitely (10-minute timeout)

### Do This
- ✅ Use provided logging functions
- ✅ Mount and unmount properly
- ✅ Check device exists first
- ✅ Print clear status messages
- ✅ Handle errors gracefully

---

## Testing

### Test Manually

```bash
sudo ./workers/my_worker.sh sdb
```

### Check Discovery

```bash
sudo python3 usb_cleaner_box.py
# Look for "Discovered worker" messages
```

### Debug Output

Workers can print debug info:

```bash
echo "[DEBUG] Mounting device..."
echo "[DEBUG] Files found: $COUNT"
```

---

## Advanced Topics

### Mounting

```bash
# Create mount point
MOUNT_POINT="/media/worker_$DEVICE"
sudo mkdir -p "$MOUNT_POINT"

# Mount first partition
sudo mount "/dev/${DEVICE}1" "$MOUNT_POINT"

# Do work...

# Always unmount
sudo umount "$MOUNT_POINT"
sudo rmdir "$MOUNT_POINT"
```

### Logging

```bash
log_message() {
    echo "[$(date '+%Y-%m-%d %H:%M:%S')] $1" | tee -a /var/log/usb_malware_scan.log
}

log_message "Worker started for $DEVICE"
```

### Progress Reporting

```bash
TOTAL=100
for i in $(seq 1 $TOTAL); do
    echo "Progress: $i/$TOTAL"
    # Do work
done
```

### Dependencies

Check if tools are installed:

```bash
if ! command -v some_tool &> /dev/null; then
    echo "ERROR: some_tool not installed"
    exit 1
fi
```

**Example - Auto-install LibreOffice:**

```bash
if ! command -v libreoffice &> /dev/null; then
    echo "Installing LibreOffice..."
    sudo apt-get update -qq
    sudo apt-get install -y libreoffice --no-install-recommends
fi
```

---

## Worker Ideas

- **File vitrification** - Convert docs to PDF, neutralize executables (built-in)
- File backup to network/cloud
- Duplicate file finder
- Photo organizer
- Document converter
- Encryption/decryption
- Hash verification
- File recovery
- Disk health check
- Permission fixer
- Metadata cleaner

---

For the complete template with all comments and examples, see [WORKER_TEMPLATE.sh](WORKER_TEMPLATE.sh).

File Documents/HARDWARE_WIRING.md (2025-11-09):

# Hardware Wiring Guide

Complete wiring diagrams and bill of materials for building the USB Cleaner Box hardware.

## Power Options

The USB Cleaner Box can be built with **two different power configurations**:

1. **9V Battery Powered** - Portable, standalone operation
2. **USB Powered** - Direct power from USB port or wall adapter

Choose the configuration that best suits your needs.

---

## Option 1: 9V Battery Powered

This configuration uses a 9V battery for portable operation. Ideal for field use or when AC power is not available.

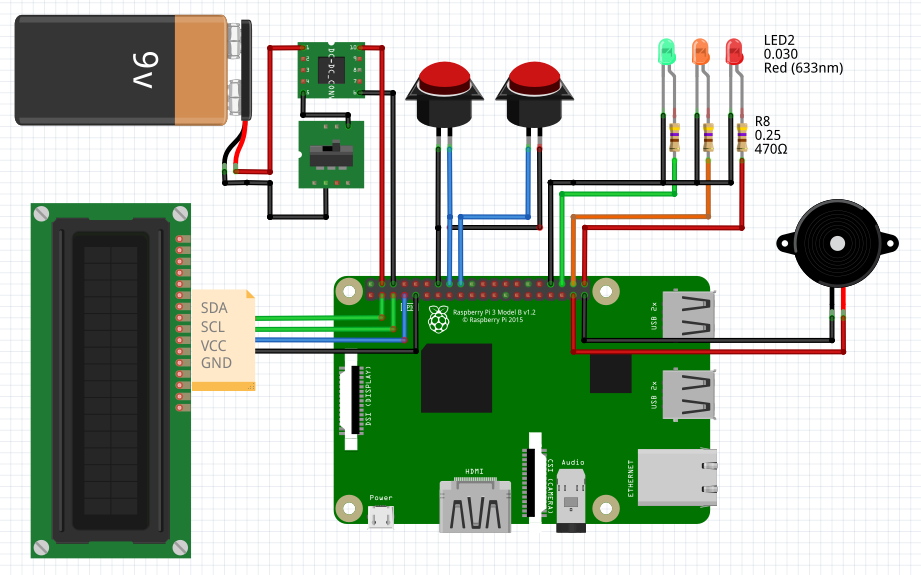
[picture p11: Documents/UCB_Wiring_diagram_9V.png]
9V Battery Powered Wiring Diagram


### Power Specifications (9V)
- **Input**: 9V battery (alkaline or rechargeable)
- **Regulation**: 5V step-down converter/regulator required
- **Current Draw**: ~500mA typical, 1A peak
- **Battery Life**: 4-6 hours with standard 9V alkaline battery

---

## Option 2: USB Powered

This configuration uses a USB power input (5V). Ideal for desktop/lab use with consistent power.

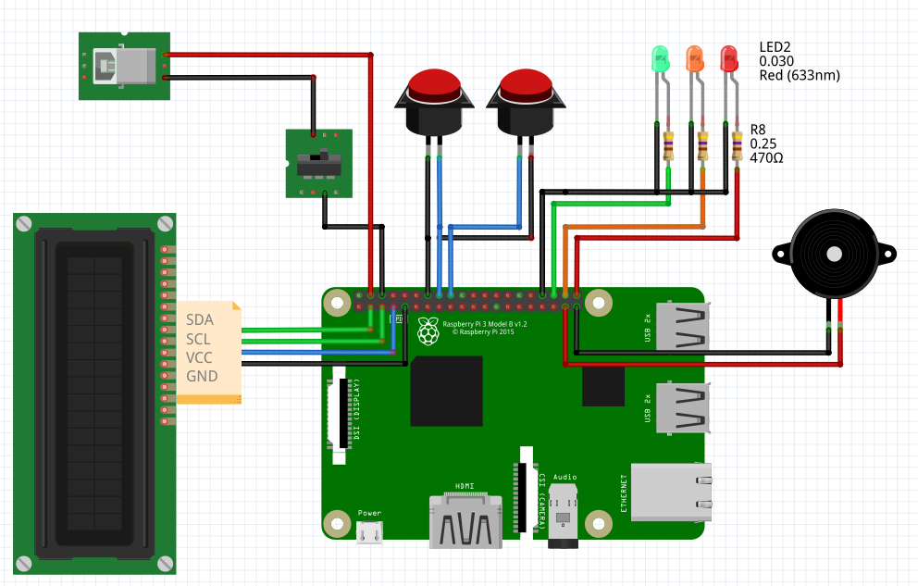
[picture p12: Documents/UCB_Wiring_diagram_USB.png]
USB Powered Wiring Diagram


### Power Specifications (USB)
- **Input**: 5V DC via USB Micro/Mini connector
- **Current Draw**: ~500mA typical, 1A peak
- **Power Source**: USB wall adapter (5V/2A recommended) or USB port

---

## Bill of Materials (BOM)

### Core Components

| Qty | Component | Description | Notes | Avg Price |
|-----|---|---|---|---|
| 1 | Raspberry Pi 3 | Main microcontroller | Or Pi Zero 2 W for better performance | 47.00€ |
| 1 | 16x2 I2C LCD Display | Character display, I2C interface | I2C address: 0x27 | 9.00€ |
| 3 | 5mm LEDs | Status indicators | 1x Green, 1x Orange, 1x Red | 0.10€ |
| 3 | 220Ω Resistors | LED current limiting | 1/4W or 1/8W | 0.05€ |
| 2 | Metal Push Buttons | User input (YES/NO) | 12mm x 12mm momentary switches | 3.00€ |
| 1 | Passive Buzzer | Audio feedback | 5V, 12mm diameter | 0.50€ |

**Core Components Subtotal: 62.95€**

### Power Supply Components

#### For 9V Battery Configuration:
| Qty | Component | Description | Notes | Avg Price |
|-----|---|---|---|---|
| 1 | 9V Battery Connector | Battery snap connector | With leads | 0.50€ |
| 1 | 9V Battery | Power source | Alkaline or rechargeable NiMH | 3.00€ |
| 1 | 5V Voltage Regulator | Step-down converter | DC-DC buck converter (more efficient) | 1.50€ |
| 1 | Metal Power Switch | On/Off control | SPST toggle or slide switch | 4.00€ |

**9V Battery Configuration Subtotal: 9.00€**

#### For USB Powered Configuration:
| Qty | Component | Description | Notes | Avg Price |
|-----|---|---|---|---|
| 1 | USB Connector | Power input | Micro USB or Mini USB | 1.50€ |
| 1 | USB Power Cable | 5V power supply | 5V/2A wall adapter recommended | 10.00€ |
| 1 | Power Switch | On/Off control (optional) | SPST toggle or slide switch | 4.00€ |

**USB Configuration Subtotal: 15.50€**

### GPIO Pin Assignments

| Component | GPIO Pin | BCM Number | Physical Pin |
|---|---|---|---|
| Green LED | GPIO16 | 16 | Pin 36 |
| Orange LED | GPIO20 | 20 | Pin 38 |
| Red LED | GPIO21 | 21 | Pin 40 |
| Left Button (NO) | GPIO23 | 23 | Pin 16 |
| Right Button (YES) | GPIO24 | 24 | Pin 18 |
| Buzzer | GPIO26 | 26 | Pin 37 |
| LCD Power Control | GPIO4 | 4 | Pin 7 |
| LCD SDA (I2C) | GPIO2 | 2 | Pin 3 |
| LCD SCL (I2C) | GPIO3 | 3 | Pin 5 |

### Enclosure & Mounting

| Qty | Component | Description | Notes | Avg Price |
|-----|---|---|---|---|
| 1 | Project Box | Enclosure | Recommended: 150x100x50mm | 30.00€ |
| 4 | M2.5 Screws | Pi mounting | 10mm length | 0.50€ |
| 4 | M2.5 Standoffs | Pi standoffs | 10mm height | 0.40€ |
| 1 | Prototype PCB or Breadboard | Component mounting | Optional, for permanent build | 3.00€ |
| 1 | Jumper Wires Set | Connections | Male-to-female, various lengths | 5.00€ |

**Enclosure & Mounting Subtotal: 38.90€**

---

## Total Cost Summary

### 9V Battery Powered Configuration:
- Core Components: **62.95€**
- Power Supply (9V): **9.00€**
- Enclosure & Mounting: **38.90€**

**Total: ~110.85€** (excluding tools)

### USB Powered Configuration:
- Core Components: **62.95€**
- Power Supply (USB): **15.50€**
- Enclosure & Mounting: **38.90€**

**Total: ~117.35€** (excluding tools)

> *Prices are approximate averages in Euros and may vary by supplier, location, and time. Bulk purchases or existing component inventory can reduce costs significantly.*

---

## Assembly Tips

### General Guidelines

1. **Test Components First**: Verify all components work individually before final assembly
2. **Check Polarity**: LEDs and buzzer are polarized - observe polarity!
3. **Secure Connections**: Use solder for permanent builds, ensure no shorts
4. **Cable Management**: Keep wires organized and away from moving parts
5. **Test Incrementally**: Test after each major component is added

### Power Supply Tips

#### 9V Battery Configuration:
- Use a DC-DC buck converter instead of LM7805 for better efficiency (longer battery life)
- Consider rechargeable 9V NiMH batteries for cost savings
- Ensure voltage regulator can handle 1A continuous current

#### USB Configuration:
- Use a quality USB power adapter (5V/2A minimum)
- Consider adding a USB power bank for portability
- Ensure USB cable is rated for at least 2A

### LCD Connection

The LCD uses I2C communication:
- **SDA** (GPIO2/Pin 3) - Data line
- **SCL** (GPIO3/Pin 5) - Clock line
- **VCC** - (GPIO4/Pin 7) - Controls LCD power via MOSFET/transistor
- **GND** - Ground

### LED Wiring

Each LED requires a current-limiting resistor:
- LED Anode (+) → 470Ω resistor → GPIO pin
- LED Cathode (-) → GND

### Button Wiring

Buttons use internal pull-up resistors:
- One terminal → GPIO pin
- Other terminal → GND
- Press button = GPIO goes LOW

---

## Safety & Precautions

⚠️ **Important Safety Information**:

1. **Power Safety**
   - Never exceed 5V on Raspberry Pi GPIO pins
   - Ensure proper polarity on all components
   - Use appropriate fuses for battery-powered builds
   - Disconnect power before making wiring changes

2. **Electrostatic Discharge (ESD)**
   - Handle Raspberry Pi with ESD precautions
   - Use anti-static wrist strap when possible
   - Avoid touching component pins unnecessarily

3. **Thermal Considerations**
   - Ensure adequate ventilation in enclosure
   - Voltage regulators may require heatsinks
   - Avoid blocking Raspberry Pi ventilation

4. **Testing**
   - Always test with multimeter before connecting to Pi
   - Verify voltage levels at all connection points
   - Check for shorts before powering on

---

## Design Files

This directory contains:

- `UCB_Wiring_diagram_9V.png` - 9V battery configuration diagram
- `UCB_Wiring_diagram_USB.png` - USB powered configuration diagram
- `UCB_9V_power.fzz` - Fritzing source file (9V configuration)
- `UCB_usb_power.fzz` - Fritzing source file (USB configuration)

**Note**: `.fzz` files can be opened and edited with [Fritzing](https://fritzing.org/)

---

## Tools Required

- Soldering iron and solder
- Wire strippers
- Multimeter
- Drill with bits (for enclosure mounting holes)
- Hot glue gun (optional, for securing components)
- Screwdrivers (Phillips and flathead)

---

## Additional Resources

- [Raspberry Pi GPIO Pinout](https://pinout.xyz/)
- [I2C LCD Tutorial](https://www.circuitbasics.com/raspberry-pi-i2c-lcd-set-up-and-programming/)
- [Fritzing Software](https://fritzing.org/)

---

For detailed hardware specifications, testing procedures, and troubleshooting, see [HARDWARE.md](HARDWARE.md).

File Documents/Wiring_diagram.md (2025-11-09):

# USB Cleaner Box - Wiring Diagrams

This directory contains the complete wiring diagrams and schematics for building the USB Cleaner Box hardware.

## Power Options

The USB Cleaner Box can be built with **two different power configurations**:

1. **9V Battery Powered** - Portable, standalone operation
2. **USB Powered** - Direct power from USB port or wall adapter

Choose the configuration that best suits your needs.

---

## Option 1: 9V Battery Powered

This configuration uses a 9V battery for portable operation. Ideal for field use or when AC power is not available.

9V Battery Powered Wiring Diagram

### Power Specifications (9V)
- **Input**: 9V battery (alkaline or rechargeable)
- **Regulation**: 5V step-down converter/regulator required
- **Current Draw**: ~500mA typical, 1A peak
- **Battery Life**: 4-6 hours with standard 9V alkaline battery

---

## Option 2: USB Powered

This configuration uses a USB power input (5V). Ideal for desktop/lab use with consistent power.

USB Powered Wiring Diagram

### Power Specifications (USB)
- **Input**: 5V DC via USB Micro/Mini connector
- **Current Draw**: ~500mA typical, 1A peak
- **Power Source**: USB wall adapter (5V/2A recommended) or USB port

---

### Tools Required

- Soldering iron and solder
- Wire strippers
- Multimeter
- Drill with bits (for enclosure mounting holes)
- Hot glue gun (optional, for securing components)
- Screwdrivers (Phillips and flathead)

---

## Assembly Notes

### General Guidelines

1. **Test Components First**: Verify all components work individually before final assembly
2. **Check Polarity**: LEDs and buzzer are polarized - observe polarity!
3. **Secure Connections**: Use solder for permanent builds, ensure no shorts
4. **Cable Management**: Keep wires organized and away from moving parts
5. **Test Incrementally**: Test after each major component is added

### Power Supply Tips

#### 9V Battery Configuration:
- Use a DC-DC buck converter instead of LM7805 for better efficiency (longer battery life)
- Consider rechargeable 9V NiMH batteries for cost savings
- Ensure voltage regulator can handle 1A continuous current

#### USB Configuration:
- Use a quality USB power adapter (5V/2A minimum)
- Consider adding a USB power bank for portability
- Ensure USB cable is rated for at least 2A

### GPIO Pin Assignments

| Component | GPIO Pin | BCM Number | Physical Pin |
|---|---|---|---|
| Green LED | GPIO16 | 16 | Pin 36 |
| Orange LED | GPIO20 | 20 | Pin 38 |
| Red LED | GPIO21 | 21 | Pin 40 |
| Left Button (NO) | GPIO23 | 23 | Pin 16 |
| Right Button (YES) | GPIO24 | 24 | Pin 18 |
| Buzzer | GPIO26 | 26 | Pin 37 |
| LCD Power Control | GPIO4 | 4 | Pin 7 |
| LCD SDA (I2C) | GPIO2 | 2 | Pin 3 |
| LCD SCL (I2C) | GPIO3 | 3 | Pin 5 |

### LCD Connection

The LCD uses I2C communication:
- **SDA** (GPIO2/Pin 3) - Data line
- **SCL** (GPIO3/Pin 5) - Clock line
- **VCC** - (GPIO4/Pin 7) - Controls LCD power via MOSFET/transistor
- **GND** - Ground

### LED Wiring

Each LED requires a current-limiting resistor:
- LED Anode (+) → 470Ω resistor → GPIO pin
- LED Cathode (-) → GND

### Button Wiring

Buttons use internal pull-up resistors:
- One terminal → GPIO pin
- Other terminal → GND
- Press button = GPIO goes LOW

---

## Safety & Precautions

⚠️ **Important Safety Information**:

1. **Power Safety**
   - Never exceed 5V on Raspberry Pi GPIO pins
   - Ensure proper polarity on all components
   - Use appropriate fuses for battery-powered builds
   - Disconnect power before making wiring changes

2. **Electrostatic Discharge (ESD)**
   - Handle Raspberry Pi with ESD precautions
   - Use anti-static wrist strap when possible
   - Avoid touching component pins unnecessarily

3. **Thermal Considerations**
   - Ensure adequate ventilation in enclosure
   - Voltage regulators may require heatsinks
   - Avoid blocking Raspberry Pi ventilation

4. **Testing**
   - Always test with multimeter before connecting to Pi
   - Verify voltage levels at all connection points
   - Check for shorts before powering on

---

## Design Files

This directory contains:

- `UCB_Wiring_diagram_9V.png` - 9V battery configuration
- `UCB_Wiring_diagram_USB.png` - USB powered configuration
- `UCB_9V_power.fzz` - Fritzing source file (9V)
- `UCB_usb_power.fzz` - Fritzing source file (USB)

**Note**: `.fzz` files can be opened and edited with [Fritzing](https://fritzing.org/)

---

## Additional Resources

- [Raspberry Pi GPIO Pinout](https://pinout.xyz/)
- [I2C LCD Tutorial](https://www.circuitbasics.com/raspberry-pi-i2c-lcd-set-up-and-programming/)
- [Fritzing Software](https://fritzing.org/)

---

## License

Hardware designs are open source. Feel free to modify and adapt for your needs.

## Contributing

Found an issue or have an improvement? Please open an issue or submit a pull request!

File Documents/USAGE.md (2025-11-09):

# USB Cleaner Box - Usage Guide

## Quick Start

```bash
cd /home/antoine/raspberry/BNU/UCB
sudo ./start.sh
```

## Application Flow

```
┌─────────────────────────────────────────────────────────┐
│                    STARTUP SEQUENCE                      │
├─────────────────────────────────────────────────────────┤
│ LCD:  "USB drive"      / "Cleaner Box"                  │
│ LEDs: Snake animation (Green→Orange→Red→Orange) x2      │
│ Sound: SNCF startup jingle                              │
└─────────────────────────────────────────────────────────┘
                          ↓
┌─────────────────────────────────────────────────────────┐
│                  WAITING FOR USB                        │
├─────────────────────────────────────────────────────────┤
│ LCD:  "Insert USB"     / "drive..."                     │
│ LEDs: All OFF                                           │
└─────────────────────────────────────────────────────────┘
                          ↓
                  [USB PLUGGED IN]
                          ↓
┌─────────────────────────────────────────────────────────┐
│                   USB DETECTED                          │
├─────────────────────────────────────────────────────────┤
│ LCD:  "USB detected"   / "[size]"                       │
│ Sound: Warning beeps (3x)                               │
└─────────────────────────────────────────────────────────┘
                          ↓
┌─────────────────────────────────────────────────────────┐
│              QUESTION 1: Full Analysis                  │
├─────────────────────────────────────────────────────────┤
│ LCD:  "Full analysis?" / "NO           YES"             │
│                                                         │
│ [LEFT button = NO] ────────┐  [RIGHT button = YES]     │
│         Skip               │         ↓                  │
└────────────────────────────┼─────────────────────────────┘
                             │         ↓
                             │  ┌──────────────────────┐
                             │  │  RUN MALWARE SCAN    │
                             │  │  (ClamAV analysis)   │
                             │  │  LCD: "Analyzing"    │
                             │  │       "malware..."   │
                             │  └──────────────────────┘
                             │         ↓
                             └─────────┴─────────────────────┐
                                                             ↓
┌─────────────────────────────────────────────────────────┐
│           QUESTION 2: Executable Check                  │
├─────────────────────────────────────────────────────────┤
│ LCD:  "Executable chk?" / "NO           YES"            │
│                                                         │
│ [LEFT button = NO] ────────┐  [RIGHT button = YES]     │
│         Skip               │         ↓                  │
└────────────────────────────┼─────────────────────────────┘
                             │         ↓
                             │  ┌──────────────────────┐
                             │  │ CHECK EXECUTABLES    │
                             │  │ (PE/ELF/Scripts)     │
                             │  │ LCD: "Checking"      │
                             │  │      "executables"   │
                             │  └──────────────────────┘
                             │         ↓
                             └─────────┴─────────────────────┐
                                                             ↓
┌─────────────────────────────────────────────────────────┐
│              QUESTION 3: Format USB                     │
├─────────────────────────────────────────────────────────┤
│ LCD:  "Format USB?"    / "NO           YES"             │
│                                                         │
│ [LEFT button = NO] ────────┐  [RIGHT button = YES]     │
│         Skip               │         ↓                  │
└────────────────────────────┼─────────────────────────────┘
                             │         ↓
                             │  ┌──────────────────────┐
                             │  │ CONFIRM FORMAT       │
                             │  │ LCD: "Confirm fmt?"  │
                             │  │      "NO        YES" │
                             │  └──────────────────────┘
                             │         ↓
                             │    [YES pressed]
                             │         ↓
                             │  ┌──────────────────────┐
                             │  │   FORMAT USB         │
                             │  │   (FAT32, secure)    │
                             │  │   LCD: "Formatting"  │
                             │  │        "USB drive"   │
                             │  └──────────────────────┘
                             │         ↓
                             └─────────┴─────────────────────┐
                                                             ↓

         ┌──────────────────────────────────────────────────┐
         │               RESULTS DISPLAY                    │
         └──────────────────────────────────────────────────┘
                          ↓
    ┌────────────────────┼────────────────────┐
    ↓                    ↓                    ↓
┌─────────┐      ┌──────────────┐     ┌─────────────┐
│ THREAT  │      │  UNCERTAIN   │     │   CLEAN     │
│ FOUND   │      │              │     │             │
├─────────┤      ├──────────────┤     ├─────────────┤
│ Malware │      │ Scan error / │     │ No threats  │
│   OR    │      │ Timeout /    │     │ No malware  │
│ Executables    │ Incomplete   │     │ No execs    │
├─────────┤      ├──────────────┤     ├─────────────┤
│ LCD:    │      │ LCD:         │     │ LCD:        │
│ "THREAT"│      │ "UNCERTAIN"  │     │ "USB is"    │
│ "DETECTED"     │ "result"     │     │ "CLEAN!"    │
├─────────┤      ├──────────────┤     ├─────────────┤
│ LED:    │      │ LED:         │     │ LED:        │
│ RED     │      │ ORANGE       │     │ GREEN       │
│ blinking│      │ blinking     │     │ blinking    │
│ 5 sec   │      │ 5 sec        │     │ 5 sec       │
├─────────┤      ├──────────────┤     ├─────────────┤
│ Sound:  │      │ Sound:       │     │ Sound:      │
│ Failed  │      │ Warning      │     │ Success     │
│ jingle  │      │ beeps        │     │ jingle      │
├─────────┤      ├──────────────┤     ├─────────────┤
│ Final:  │      │ Final:       │     │ Final:      │
│"DO NOT" │      │ "Use with"   │     │"Safe to use"│
│"USE!"   │      │ "caution"    │     │             │
└─────────┘      └──────────────┘     └─────────────┘
    │                    │                    │
    └────────────────────┴────────────────────┘
                          ↓
              ┌──────────────────────┐
              │  READY FOR NEXT USB  │
              │  (Loop back to wait) │
              └──────────────────────┘
```

## Button Reference

```
┌─────────────────────────────────────────┐
│  LEFT Button (GPIO23)  │ RIGHT Button  │
│                        │   (GPIO24)    │
├────────────────────────┼───────────────┤
│        NO              │      YES      │
│      Cancel            │    Confirm    │
│       Skip             │    Proceed    │
└────────────────────────┴───────────────┘
```

## LED Status Meanings

```
┌──────────┬─────────────────────────────────┐
│   LED    │          Meaning                │
├──────────┼─────────────────────────────────┤
│  GREEN   │ Safe / Clean / Success          │
│  ORANGE  │ Processing / Warning / Uncertain│
│  RED     │ Threat / Danger / Error         │
│  Snake   │ Startup animation               │
└──────────┴─────────────────────────────────┘
```

## Sound Signals

```
┌────────────────┬──────────────────────────┐
│     Sound      │         When             │
├────────────────┼──────────────────────────┤
│ SNCF Jingle    │ Application startup      │
│ Warning Beeps  │ USB detected / Uncertain │
│ Success Jingle │ Clean scan result        │
│ Failed Jingle  │ Threat detected          │
└────────────────┴──────────────────────────┘
```

## Example Session

**User plugs in USB drive:**

1. LCD shows: "USB detected" / "8.0G"
2. Beep beep beep (warning sound)
3. LCD shows: "Full analysis?" / "NO           YES"
4. User presses RIGHT button (YES)
5. LCD shows: "Analyzing" / "malware..."
   - Progress updates during scan
6. LCD shows: "Executable chk?" / "NO           YES"
7. User presses RIGHT button (YES)
8. LCD shows: "Checking" / "executables..."
9. LCD shows: "Format USB?" / "NO           YES"
10. User presses LEFT button (NO)
11. LCD shows: "USB is" / "CLEAN!"
12. GREEN LED blinks for 5 seconds
13. Success jingle plays
14. LCD shows: "Safe to use!" / ""
15. Back to: "Insert USB" / "drive..."

## Installation as Service

To run USB Cleaner Box automatically at boot:

```bash
# Copy service file
sudo cp /home/antoine/raspberry/BNU/UCB/usb-cleaner-box.service /etc/systemd/system/

# Reload systemd
sudo systemctl daemon-reload

# Enable service
sudo systemctl enable usb-cleaner-box.service

# Start service
sudo systemctl start usb-cleaner-box.service

# Check status
sudo systemctl status usb-cleaner-box.service

# View logs
sudo journalctl -u usb-cleaner-box.service -f
```

## Manual Run (for testing)

```bash
cd /home/antoine/raspberry/BNU/UCB
sudo python3 usb_cleaner_box.py
```

## Stopping the Application

- Press `Ctrl+C` in the terminal
- Or if running as service: `sudo systemctl stop usb-cleaner-box.service`

## Tips

1. **First time setup**: Test each component separately
   - LCD: `python3 lcd_helper.py`
   - LEDs: Check with existing LED test scripts
   - Buttons: Use the button test script
   - Sound: Test with play_sncf_jingle.py

2. **Always run with sudo**: GPIO access requires root privileges

3. **Update virus definitions regularly**:
   ```bash
   sudo systemctl stop clamav-freshclam
   sudo freshclam
   sudo systemctl start clamav-freshclam
   ```

4. **Monitor logs**: Keep an eye on `/var/log/usb_malware_scan.log`

5. **Testing without USB**: You can modify the code to simulate USB insertion for testing

## Troubleshooting Quick Reference

| Issue | Solution |
|---|---|
| LCD blank | Check I2C: `sudo i2cdetect -y 1` |
| No USB detection | Run with sudo, check `lsblk` |
| LEDs not working | Verify GPIO pin numbers |
| No sound | Check buzzer on GPIO26 |
| Buttons unresponsive | Check GPIO23/24 connections |
| Scan fails | Ensure ClamAV installed: `clamscan --version` |
| Format fails | Check USB not mounted elsewhere |

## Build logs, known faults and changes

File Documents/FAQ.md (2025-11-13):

# Frequently Asked Questions (FAQ)

Common questions and answers about the USB Cleaner Box.

## General Questions

### What is the USB Cleaner Box?

The USB Cleaner Box is an interactive USB security scanning and cleaning system built on Raspberry Pi. It allows you to scan USB drives for malware, check for suspicious executables, and securely format drives - all through a simple LCD interface with button controls.

### Who is this for?

- IT professionals who need to scan USB drives regularly
- Security-conscious users who want to check unknown USB drives
- Anyone who handles USB drives from untrusted sources
- Educational institutions teaching cybersecurity
- Home users who want extra protection

### How does it work?

1. Insert a USB drive
2. Answer YES/NO questions on the LCD display
3. Workers (scripts) run based on your choices
4. Results shown via LED colors, sounds, and LCD messages
5. Remove USB when prompted

### Is it safe to use?

Yes! The device is designed for safety:
- Read-only scanning by default
- Format only with confirmation
- All operations logged
- No network connection required
- Open-source code you can review

---

## Hardware Questions

### What hardware do I need?

**Minimum**:
- Raspberry Pi (Pi 3/4 or Zero 2 W)
- 16x2 I2C LCD display
- 3 LEDs (green, orange, red)
- 2 push buttons
- Passive buzzer
- Power supply (9V battery or USB)

See [Hardware Guide](HARDWARE.md) for complete list.

### Can I use a Raspberry Pi Zero W?

Yes, but it will be slower. Pi Zero 2 W is recommended for better performance. Regular Pi Zero (without W) works but you'll lose wireless capabilities.

### What if my LCD has a different I2C address?

Edit `lcd_helper.py` and change:
```python
I2C_ADDR = 0x27  # Change to your address
```

Find your address with:
```bash
sudo i2cdetect -y 1
```

### Can I use different GPIO pins?

Yes! Edit the respective Python modules to change pin assignments. Make sure to update both code and wiring.

### How much power does it use?

- Idle: ~150mA (~0.75W)
- Scanning: ~500mA (~2.5W)
- Peak: ~700mA (~3.5W)

Use a 2A power supply to be safe.

### How long does a 9V battery last?

Typical 9V alkaline battery (500-600mAh):
- 4-6 hours of active use
- Longer with rechargeable NiMH batteries
- Use DC-DC converter for better efficiency

---

## Software Questions

### What operating system do I need?

Raspberry Pi OS (formerly Raspbian). The latest version is recommended.

### Do I need internet connection?

Only for initial setup and updating virus definitions. The device works offline for scanning.

### How do I update virus definitions?

```bash
sudo freshclam
```

Run this weekly for best protection.

### Can I add my own workers?

Yes! The worker system is extensible. Create a shell script in `workers/` directory with proper metadata. See [Worker Guide](WORKER_GUIDE.md).

### How do I enable or disable workers?

Edit the worker file and change the `WORKER_ENABLED` line:

```bash
# Disable a worker
nano workers/format_usb.sh
# Change: WORKER_ENABLED=false

# Restart service
sudo systemctl restart usb-cleaner-box.service
```

Disabled workers are skipped - their questions won't appear on the LCD.

### Can I disable a worker temporarily?

Yes! Set `WORKER_ENABLED=false` in the worker file. You can re-enable it later by changing it back to `true`. This is useful for:
- Testing new workers without interference
- Temporarily disabling problematic workers
- Running only specific workers you need

### Where are scan results stored?

Log file: `/var/log/usb_malware_scan.log`

View with:
```bash
sudo tail -f /var/log/usb_malware_scan.log
```

### Can I run this without the LCD?

Technically yes, but you won't see prompts or results. The LCD is essential for the interactive interface. You could modify the code to use only terminal output.

---

## Usage Questions

### How long does a scan take?

Depends on USB size and worker:
- **Executable check**: 30-120 seconds
- **Vitrification**: 2-10 minutes (depends on document count)
- **Small USB (< 1GB)**: 2-5 minutes
- **Medium USB (1-8GB)**: 5-10 minutes
- **Large USB (> 8GB)**: 10-30 minutes
- **Format**: 30-120 seconds

### What file types can it detect?

**Malware scan** (ClamAV):
- Viruses, trojans, worms
- Ransomware
- Adware, spyware
- Malicious scripts
- And more (5+ million signatures)

**Executable check**:
- Windows: .exe, .dll, .sys, .scr, .com, .bat, .cmd, .msi
- Linux: ELF binaries
- Scripts: .sh, .ps1, .vbs, .js, .wsf, .hta

**Vitrification worker**:
- Converts: .doc, .docx, .xls, .xlsx, .ppt, .pptx, .odt, .ods, .odp, .rtf → PDF
- Neutralizes: All other files get .hold extension (except safe formats)
- Preserves: .pdf, .txt, .md, .jpg, .jpeg, .png, .gif, .bmp, .mp3, .mp4, .avi, .mkv

### Does it clean infected files?

No, the malware scanner only detects them. The recommended action is to format the USB drive if malware is detected. However, the **vitrification worker** can neutralize threats by converting documents to clean PDFs and adding .hold extensions to other files.

### Can it recover deleted files?

No, this is a security scanner, not a recovery tool. However, you could create a custom worker for file recovery.

### What if the scan times out?

The worker has a 10-minute timeout. For very large USB drives:
- Split the scan across multiple runs
- Increase timeout in `worker_manager.py`
- Use a faster Raspberry Pi model

### What is file vitrification?

Vitrification converts potentially dangerous files into safe formats:
1. **Office documents** → Clean PDF files (removes macros, scripts)
2. **Other files** → Add .hold extension (prevents execution)

This makes USB content safe to use while preserving data.

### Does vitrification delete my files?

- **Office docs**: Original files are deleted after successful PDF conversion
- **Other files**: Renamed with .hold extension (can be renamed back manually if safe)
- **Safe formats**: Left untouched (.pdf, .jpg, .txt, etc.)

### Do I need LibreOffice for vitrification?

Yes, LibreOffice is required for document-to-PDF conversion. The worker will auto-install it on first run if not present. For faster processing, install manually:

```bash
sudo apt-get install -y libreoffice --no-install-recommends
```

### Can I scan multiple USBs in a row?

Yes! After each USB:
1. Wait for "Bye bye! / Remove USB"
2. Remove first USB
3. Insert next USB
4. Process repeats

---

## Troubleshooting

### LCD shows garbage characters

**Causes**:
- Wrong I2C address
- Poor I2C connections
- Electromagnetic interference

**Solutions**:
1. Check I2C address with `sudo i2cdetect -y 1`
2. Update address in `lcd_helper.py`
3. Check SDA/SCL wiring
4. Add pull-up resistors (4.7kΩ) to I2C lines

### USB not detected

**Causes**:
- USB not recognized by system
- Permission issues
- Auto-mount conflict

**Solutions**:
1. Run with sudo: `sudo python3 usb_cleaner_box.py`
2. Check `lsblk` to see if USB appears
3. Disable auto-mount in Raspberry Pi OS
4. Check debug output in terminal

### Buttons don't respond

**Causes**:
- Wrong wiring
- Button not momentary
- GPIO conflict

**Solutions**:
1. Verify one terminal to GPIO, other to GND
2. Use momentary (not latching) buttons
3. Test buttons with simple script
4. Check internal pull-ups are enabled

### No sound from buzzer

**Causes**:
- Active buzzer instead of passive
- Missing transistor driver
- Wrong polarity

**Solutions**:
1. Use passive buzzer (not active)
2. Add NPN transistor driver circuit
3. Check buzzer polarity
4. Test buzzer directly with 5V

### ClamAV not working

**Causes**:
- Not installed
- Out of date definitions
- Insufficient memory

**Solutions**:
1. Install: `sudo apt-get install clamav`
2. Update: `sudo freshclam`
3. Use Pi with more RAM (1GB+)
4. Close other applications

### Device randomly reboots

**Causes**:
- Insufficient power
- Voltage drops
- Overheating

**Solutions**:
1. Use 2A+ power supply
2. Use shorter/thicker power cables
3. Add heatsink to voltage regulator
4. Improve ventilation

---

## Advanced Questions

### Can I run workers in parallel?

No, workers run sequentially to avoid resource conflicts and ensure accurate results.

### Can I write workers in Python?

Yes! Make the script executable with `#!/usr/bin/env python3` shebang and proper metadata. See template.

### Can I access the GPIO from workers?

Not recommended. GPIO is managed by the main application. Workers should focus on file system operations.

### Can I modify the main application?

Yes! It's open source. However, using the worker system is recommended for extensibility.

### How do I create a worker that asks multiple questions?

Workers only get one YES/NO question. For complex workflows, create multiple workers or use the worker to launch an interactive script.

### Can I disable specific built-in workers?

Remove execute permission:
```bash
chmod -x workers/worker_name.sh
```

Or delete the `# WORKER_QUESTION=` line from the worker script.

### Can this detect zero-day malware?

No. ClamAV uses signature-based detection. It can't detect brand-new, unknown malware. However, it's still effective against most threats.

### Is the formatting secure (DoD wipe)?

No, it's a quick format. For secure wiping, create a custom worker using `shred` or similar tools.

### Can I add a database of results?

Yes, create a custom worker that logs to a database. Workers have full access to the file system.

### Can I use this commercially?

Check the license. The hardware designs are open source. The software follows its own license terms.

---

## Error Messages

### "ERROR: Device /dev/sdX does not exist"

**Meaning**: USB device not found

**Solution**: Verify USB is plugged in, check `lsblk`

### "ERROR: Failed to mount device"

**Meaning**: Cannot access USB filesystem

**Solution**: USB may be corrupted, try different USB, check permissions

### "WARNING: ClamAV is not installed"

**Meaning**: Antivirus software missing

**Solution**: `sudo apt-get install clamav clamav-daemon`

### "Worker timeout after 10 minutes"

**Meaning**: Operation took too long

**Solution**: USB too large or slow, increase timeout or use faster Pi

### "Permission denied"

**Meaning**: Insufficient privileges

**Solution**: Run with sudo: `sudo python3 usb_cleaner_box.py`

---

## Performance

### How can I speed up scans?

1. Use faster Raspberry Pi (Pi 4 > Pi 3 > Pi Zero)
2. Use faster USB 3.0 drives
3. Update ClamAV to latest version
4. Reduce workers to only essential ones
5. Use faster SD card in Raspberry Pi

### Why is formatting slow?

FAT32 formatting is quick (30-120 sec). If it's slower:
- Large USB drive
- Bad sectors on USB
- Slow USB controller
- Underpowered Pi

### Can I overclock the Pi?

Yes, but not recommended:
- May cause instability during scans
- Higher power consumption
- Increased heat
- Shorter hardware lifespan

---

## Safety & Security

### Is my data at risk?

No, unless you choose to format:
- Scanning is read-only
- No files are modified
- All operations logged
- Format requires confirmation

### Can infected USB harm the device?

No. The device only scans files, doesn't execute them. Raspberry Pi OS provides isolation.

### Should I trust the results?

ClamAV is industry-standard and reliable, but:
- No antivirus is 100% accurate
- Update definitions regularly
- Use multiple security tools for critical checks
- Trust red LED warnings

### What if I accidentally format?

Data is unrecoverable with standard tools. Backup important data before using USB Cleaner Box.

### Can this device get infected?

Extremely unlikely:
- Scanning doesn't execute files
- Pi OS provides sandboxing
- No auto-run features
- Regular updates prevent vulnerabilities

---

## Customization

### Can I change the startup jingle?

Yes! Edit `sound_helper.py` and modify the `play_sncf_jingle()` function with your own note frequencies.

### Can I add more LEDs?

Yes! Add GPIO connections and update `led_control.py`. You could add status LEDs, battery indicators, etc.

### Can I use an OLED display instead?

Yes, but requires code changes. Replace LCD calls with OLED library calls. OLEDs offer more display options.

### Can I add a battery level indicator?

Yes! Add voltage divider circuit and read with ADC. Display on LCD or add status LED.

### Can I remote control it over network?

Yes, you could create a web interface or SSH access. However, physical isolation is a security feature.

---

## Support & Community

### Where can I get help?

1. Check this FAQ
2. Review documentation in `Documents/` folder
3. Check log files for errors
4. Open an issue on GitHub (if applicable)

### How do I report a bug?

Include:
- Hardware configuration
- Software version
- Steps to reproduce
- Error messages
- Log files

### Can I contribute?

Yes! Contributions welcome:
- New workers
- Bug fixes
- Documentation improvements
- Hardware designs
- Translations

### Where are updates posted?

Check the GitHub repository for:
- New releases
- Bug fixes
- Feature additions
- Security updates

---

## Glossary

**ClamAV**: Open-source antivirus engine for detecting malware

**Worker**: Modular script that performs specific tasks on USB drives

**I2C**: Communication protocol used by LCD display

**GPIO**: General Purpose Input/Output pins on Raspberry Pi

**FAT32**: File system format compatible with most devices

**Malware**: Malicious software (viruses, trojans, ransomware, etc.)

**Executable**: File that can run code (potentially dangerous)

**BCM**: Broadcom pin numbering system for Raspberry Pi GPIO

**Pull-up resistor**: Resistor that keeps GPIO pin at HIGH when button not pressed

**Passive buzzer**: Buzzer requiring frequency signal (unlike active buzzer)

---

Still have questions? Check the other documentation:
- [Usage Guide](USAGE.md)
- [Installation Guide](INSTALLATION.md)
- [Hardware Guide](HARDWARE.md)
- [Hardware Wiring](HARDWARE_WIRING.md)
- [Worker Development](WORKER_GUIDE.md)

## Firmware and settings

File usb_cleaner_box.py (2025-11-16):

#!/usr/bin/env python3
"""
usb_cleaner_box.py - Main USB Cleaner Box application

This application provides an interactive USB security scanning and cleaning system
with a dynamic worker system for extensibility.
"""

import sys
import os
import time
import threading
import RPi.GPIO as GPIO

# Add current directory to path
sys.path.insert(0, os.path.dirname(os.path.abspath(__file__)))

from lcd_helper import LCD
from led_control import LEDController
from sound_helper import SoundPlayer
from button_input import ButtonInput
from usb_detection import USBDetector
from worker_manager import WorkerManager
from log_helper import log_message, log_session_banner, log_worker_choice, log_separator
from lcd_ipc import LCDIPCMonitor

# Get script directory
SCRIPT_DIR = os.path.dirname(os.path.abspath(__file__))
WORKERS_DIR = os.path.join(SCRIPT_DIR, "workers")

class USBCleanerBox:
    """Main USB Cleaner Box application class"""

    def __init__(self):
        """Initialize all hardware components"""
        print("Initializing USB Cleaner Box...")

        # Initialize hardware components
        self.lcd = LCD()
        self.leds = LEDController()
        self.sound = SoundPlayer()
        self.buttons = ButtonInput()
        self.usb = USBDetector()

        # Initialize worker manager
        self.worker_manager = WorkerManager(WORKERS_DIR)

        # Initialize LCD IPC monitor for worker communications
        self.lcd_monitor = LCDIPCMonitor(self.lcd)
        self.lcd_monitor.start()

        # State variables
        self.current_device = None

    def startup_sequence(self):
        """Perform startup sequence with LCD, LEDs, and sound"""
        print("Running startup sequence...")

        # Turn on LCD and display welcome message
        self.lcd.init()
        self.lcd.display("    BOITIER     ", " NETTOYAGE USB  ")

        # Run jingle and LED animation simultaneously using threads
        jingle_thread = threading.Thread(target=self.sound.play_sncf_jingle)
        led_thread = threading.Thread(target=self.leds.snake_blocking, kwargs={'duration': 2.4, 'speed': 0.2})

        # Start both threads at the same time
        jingle_thread.start()
        led_thread.start()

        # Wait for both to complete
        jingle_thread.join()
        led_thread.join()

        print("Startup complete!")

    def wait_for_usb(self):
        """Wait for USB device to be plugged in"""
        print("Waiting for USB device...")
        self.lcd.display("  Inserer une   ", "    clé USB...  ")
        self.leds.all_off()

        # Wait for USB device
        device = self.usb.wait_for_usb()

        if device:
            print(f"USB device detected: {device}")
            self.current_device = device

            # Get comprehensive device info
            info = self.usb.get_device_info(device)
            print(f"Device info: {info}")

            # Log session banner with full device details
            log_session_banner(info)

            # Display detection message
            self.lcd.display("USB detectee", f"{info['size']}")
            self.sound.play_beep()
            time.sleep(2)

            return True
        return False

    def ask_question(self, question):
        """
        Ask a yes/no question on LCD and wait for button input.
        Returns: True (YES), False (NO)
        """
        # Ensure question is max 16 chars
        question = question[:16]

        # Display question
        self.lcd.display(question, "NON         OUI")

        # Orange LED for question
        self.leds.orange_on()

        print(f"Question: {question}")
        print("Waiting for user input (LEFT=NO, RIGHT=YES)...")

        # Wait for button press
        answer = self.buttons.wait_for_yes_no()

        if answer is True:
            print("User answered: YES")
            self.leds.green_on()
            time.sleep(0.3)
            return True
        else:
            print("User answered: NO")
            self.leds.red_on()
            time.sleep(0.3)
            return False

    def run_worker(self, worker):
        """Run a worker script"""
        print(f"\n{'='*50}")
        print(f"Running worker: {worker.name}")
        print(f"Description: {worker.description}")
        print(f"{'='*50}\n")

        self.lcd.display("  Traitement   ", "  En cours...  ")
        self.leds.orange_on()

        # Run the worker
        result = worker.run(self.current_device)

        print(f"\nWorker completed: {worker.name}")
        print(f"Success: {result['success']}")
        print(f"Return code: {result['returncode']}")

        if result['stdout']:
            print(f"Output:\n{result['stdout']}")

        if result['stderr']:
            print(f"Errors:\n{result['stderr']}")

        return result

    def analyze_worker_result(self, worker, result):
        """Analyze worker result and return status"""
        if not result['success']:
            return 'error'

        # Check output for keywords
        output = result['stdout'].lower()

        # Check for malware/threats first (highest priority)
        if 'infected' in output or 'malware' in output or 'threat' in output:
            return 'threat'

        # Check for clean/success (before checking warnings)
        if 'clean:' in output or 'safe' in output:
            return 'clean'

        # Check for "no ... found" pattern (clean result)
        if 'found' in output and 'no' in output:
            # Check if "no" appears before "found" in the text
            if output.find('no') < output.find('found'):
                return 'clean'

        # Check for suspicious findings
        if 'suspicious' in output or 'warning:' in output:
            return 'warning'

        # Check for general "no" in output (clean)
        if 'no' in output and 'warning' not in output:
            return 'clean'

        # Default to uncertain
        return 'uncertain'

    def show_worker_result(self, worker, result):
        """Show result of a worker with LED and sound feedback"""
        status = self.analyze_worker_result(worker, result)

        print(f"\n=== WORKER RESULT: {status.upper()} ===")

        if status == 'threat':
            # Threat detected - RED blinking
            self.lcd.display("MENACE", "DETECTEE!")
            # Run LED and sound simultaneously
            led_thread = threading.Thread(target=self.leds.blink_red, kwargs={'duration': 3.0, 'speed': 0.3})
            sound_thread = threading.Thread(target=self.sound.play_failed)
            led_thread.start()
            sound_thread.start()
            led_thread.join()
            sound_thread.join()
            time.sleep(2)

        elif status == 'warning':
            # Warning - ORANGE blinking
            self.lcd.display("ALERTE", "Verif. result")
            # Run LED and sound simultaneously
            led_thread = threading.Thread(target=self.leds.blink_orange, kwargs={'duration': 3.0, 'speed': 0.5})
            sound_thread = threading.Thread(target=self.sound.play_warning)
            led_thread.start()
            sound_thread.start()
            led_thread.join()
            sound_thread.join()
            time.sleep(2)

        elif status == 'error':
            # Error - RED blinking
            self.lcd.display("ERREUR", "Echec worker")
            # Run LED and sound simultaneously
            led_thread = threading.Thread(target=self.leds.blink_red, kwargs={'duration': 3.0, 'speed': 0.5})
            sound_thread = threading.Thread(target=self.sound.play_failed)
            led_thread.start()
            sound_thread.start()
            led_thread.join()
            sound_thread.join()
            time.sleep(2)

        else:
            # Clean or uncertain - GREEN blinking
            self.lcd.display("Termine", "Succes!")
            # Run LED and sound simultaneously
            led_thread = threading.Thread(target=self.leds.blink_green, kwargs={'duration': 3.0, 'speed': 0.5})
            sound_thread = threading.Thread(target=self.sound.play_success)
            led_thread.start()
            sound_thread.start()
            led_thread.join()
            sound_thread.join()
            time.sleep(2)

    def process_usb(self):
        """Process USB with available workers"""
        # Get only enabled workers
        workers = self.worker_manager.get_workers(include_disabled=False)

        if not workers:
            print("No enabled workers available!")
            self.lcd.display("Pas de workers", "disponibles")
            time.sleep(2)
            return

        print(f"\nEnabled workers: {len(workers)}")
        for worker in workers:
            print(f"  - {worker}")

        # Process each worker
        for worker in workers:
            # Ask if user wants to run this worker
            answer = self.ask_question(worker.question)

            # Log the user's choice
            log_worker_choice(worker.name, answer)

            if answer:
                # Run the worker
                result = self.run_worker(worker)

                # Show result
                self.show_worker_result(worker, result)
            else:
                print(f"Skipping worker: {worker.name}")

            # Small delay between workers
            time.sleep(0.5)

    def goodbye_sequence(self):
        """Show goodbye message and cleanup"""
        print("\n=== Goodbye ===")
        self.lcd.display("   Au revoir    ", "Retirer cle USB")
        self.leds.snake_blocking(duration=2.0, speed=0.2)
        time.sleep(2)

    def main_loop(self):
        """Main application loop"""
        print("\n=== Entering main loop ===")

        while True:
            try:
                # Reset state
                self.current_device = None

                # Wait for USB device
                if not self.wait_for_usb():
                    continue

                # Process USB with workers
                self.process_usb()

                # Ask if user wants to run another worker
                while True:
                    if self.ask_question("Recommencer?"):
                        # Ask which workers to run again
                        self.process_usb()
                    else:
                        break

                # Update device list before goodbye (to track current state)
                self.usb.update_device_list()

                # Goodbye sequence
                self.goodbye_sequence()

                # Wait for USB to be removed before continuing
                print("Waiting for USB to be removed...")
                while self.current_device in self.usb.get_usb_devices():
                    time.sleep(0.5)

                # Update device list after removal
                self.usb.update_device_list()

                print("\n=== Ready for next USB device ===\n")

            except KeyboardInterrupt:
                print("\nShutdown requested by user")
                break
            except Exception as e:
                print(f"Error in main loop: {e}")
                import traceback
                traceback.print_exc()
                try:
                    self.lcd.display("Erreur System", "Redemarrage...")
                    time.sleep(2)
                except:
                    pass

    def cleanup(self):
        """Cleanup all resources"""
        print("Cleaning up...")
        try:
            self.lcd_monitor.stop()
        except Exception as e:
            print(f"Warning: LCD monitor cleanup error: {e}")

        try:
            self.leds.cleanup()
        except Exception as e:
            print(f"Warning: LED cleanup error: {e}")

        try:
            self.sound.cleanup()
        except Exception as e:
            print(f"Warning: Sound cleanup error: {e}")

        try:
            self.buttons.cleanup()
        except Exception as e:
            print(f"Warning: Button cleanup error: {e}")

        try:
            self.lcd.off()
        except Exception as e:
            print(f"Warning: LCD cleanup error: {e}")

        try:
            GPIO.cleanup()
        except Exception as e:
            print(f"Warning: GPIO cleanup error: {e}")

        print("Cleanup complete")

    def run(self):
        """Run the complete application"""
        try:
            # Startup sequence
            self.startup_sequence()

            # Enter main loop
            self.main_loop()

        except KeyboardInterrupt:
            print("\nApplication interrupted by user")
        except Exception as e:
            print(f"Fatal error: {e}")
            import traceback
            traceback.print_exc()
            try:
                self.lcd.display("Erreur Fatale", "Arret systeme")
                time.sleep(2)
            except:
                # LCD not available, just continue to cleanup
                pass
        finally:
            # Always cleanup
            self.cleanup()


def main():
    """Main entry point"""
    print("=" * 50)
    print("USB Cleaner Box - Starting...")
    print("=" * 50)

    app = USBCleanerBox()
    app.run()

    print("=" * 50)
    print("USB Cleaner Box - Shutdown complete")
    print("=" * 50)


if __name__ == '__main__':
    main()

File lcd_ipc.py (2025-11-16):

#!/usr/bin/env python3
"""
lcd_ipc.py - IPC mechanism for LCD display updates from workers
"""

import os
import time
import threading
import json
from pathlib import Path

LCD_COMMAND_FILE = "/tmp/ucb_lcd_command"

class LCDIPCMonitor:
    """Monitor for LCD commands from worker scripts"""

    def __init__(self, lcd):
        self.lcd = lcd
        self.running = False
        self.thread = None

    def start(self):
        """Start monitoring for LCD commands"""
        self.running = True
        self.thread = threading.Thread(target=self._monitor_loop, daemon=True)
        self.thread.start()

    def stop(self):
        """Stop monitoring"""
        self.running = False
        if self.thread:
            self.thread.join(timeout=1.0)

    def _monitor_loop(self):
        """Monitor loop that checks for LCD commands"""
        last_mtime = 0

        while self.running:
            try:
                # Check if command file exists and has been modified
                if os.path.exists(LCD_COMMAND_FILE):
                    current_mtime = os.path.getmtime(LCD_COMMAND_FILE)

                    if current_mtime > last_mtime:
                        last_mtime = current_mtime

                        # Read and execute command
                        with open(LCD_COMMAND_FILE, 'r') as f:
                            content = f.read().strip()

                        if content:
                            try:
                                # Parse command (JSON format: {"line1": "...", "line2": "..."})
                                cmd = json.loads(content)
                                line1 = cmd.get('line1', '')
                                line2 = cmd.get('line2', '')

                                # Update LCD
                                self.lcd.display(line1, line2)

                            except json.JSONDecodeError:
                                # Fallback: treat as simple two-line format
                                lines = content.split('\n', 1)
                                line1 = lines[0] if len(lines) > 0 else ''
                                line2 = lines[1] if len(lines) > 1 else ''
                                self.lcd.display(line1, line2)

            except Exception as e:
                # Silently ignore errors to avoid disrupting main app
                pass

            # Check every 100ms
            time.sleep(0.1)


def send_lcd_command(line1, line2=""):
    """Send LCD command from worker script"""
    try:
        cmd = {
            'line1': line1,
            'line2': line2
        }
        with open(LCD_COMMAND_FILE, 'w') as f:
            json.dump(cmd, f)
            f.flush()
            os.fsync(f.fileno())
    except Exception:
        pass  # Silently fail if unable to send command


if __name__ == "__main__":
    import sys
    # Allow calling from command line: python3 lcd_ipc.py "Line 1" "Line 2"
    if len(sys.argv) >= 2:
        line1 = sys.argv[1]
        line2 = sys.argv[2] if len(sys.argv) >= 3 else ""
        send_lcd_command(line1, line2)

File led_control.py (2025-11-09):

#!/usr/bin/env python3
"""
led_control.py - LED control module for USB Cleaner Box
"""

import RPi.GPIO as GPIO
import time
import threading

# LED pin assignments
GREEN_LED_PIN = 16
ORANGE_LED_PIN = 20
RED_LED_PIN = 21

class LEDController:
    """LED controller class for managing RGB LEDs"""

    def __init__(self):
        # Set up GPIO mode (BCM mode)
        GPIO.setmode(GPIO.BCM)

        # Set GPIO pins as output
        GPIO.setup(GREEN_LED_PIN, GPIO.OUT)
        GPIO.setup(ORANGE_LED_PIN, GPIO.OUT)
        GPIO.setup(RED_LED_PIN, GPIO.OUT)

        # Initialize all LEDs to OFF
        GPIO.output(GREEN_LED_PIN, GPIO.LOW)
        GPIO.output(ORANGE_LED_PIN, GPIO.LOW)
        GPIO.output(RED_LED_PIN, GPIO.LOW)

        self.stop_animation = False
        self.animation_thread = None

    def all_off(self):
        """Turn off all LEDs"""
        self.stop_animation = True
        if self.animation_thread and self.animation_thread.is_alive():
            self.animation_thread.join()

        GPIO.output(GREEN_LED_PIN, GPIO.LOW)
        GPIO.output(ORANGE_LED_PIN, GPIO.LOW)
        GPIO.output(RED_LED_PIN, GPIO.LOW)

    def green_on(self):
        """Turn on green LED only"""
        self.all_off()
        GPIO.output(GREEN_LED_PIN, GPIO.HIGH)

    def orange_on(self):
        """Turn on orange LED only"""
        self.all_off()
        GPIO.output(ORANGE_LED_PIN, GPIO.HIGH)

    def red_on(self):
        """Turn on red LED only"""
        self.all_off()
        GPIO.output(RED_LED_PIN, GPIO.HIGH)

    def _snake_animation(self, duration=2.0, speed=0.2):
        """Internal method to run snake animation"""
        self.stop_animation = False
        start_time = time.time()

        while not self.stop_animation and (time.time() - start_time) < duration:
            # Green LED on
            GPIO.output(GREEN_LED_PIN, GPIO.HIGH)
            time.sleep(speed)
            GPIO.output(GREEN_LED_PIN, GPIO.LOW)

            if self.stop_animation:
                break

            # Orange LED on
            GPIO.output(ORANGE_LED_PIN, GPIO.HIGH)
            time.sleep(speed)
            GPIO.output(ORANGE_LED_PIN, GPIO.LOW)

            if self.stop_animation:
                break

            # Red LED on
            GPIO.output(RED_LED_PIN, GPIO.HIGH)
            time.sleep(speed)
            GPIO.output(RED_LED_PIN, GPIO.LOW)

            if self.stop_animation:
                break

            # Orange LED on (reverse)
            GPIO.output(ORANGE_LED_PIN, GPIO.HIGH)
            time.sleep(speed)
            GPIO.output(ORANGE_LED_PIN, GPIO.LOW)

        self.all_off()

    def snake(self, duration=2.0, speed=0.2):
        """Run LED snake animation for specified duration"""
        self.all_off()
        self.animation_thread = threading.Thread(
            target=self._snake_animation,
            args=(duration, speed)
        )
        self.animation_thread.start()

    def snake_blocking(self, duration=2.0, speed=0.2):
        """Run LED snake animation (blocking)"""
        self.all_off()
        self._snake_animation(duration, speed)

    def _blink_animation(self, pin, duration=3.0, speed=0.5):
        """Internal method to blink a specific LED"""
        self.stop_animation = False
        start_time = time.time()

        while not self.stop_animation and (time.time() - start_time) < duration:
            GPIO.output(pin, GPIO.HIGH)
            time.sleep(speed)
            if self.stop_animation:
                break
            GPIO.output(pin, GPIO.LOW)
            time.sleep(speed)

        GPIO.output(pin, GPIO.LOW)

    def blink_red(self, duration=3.0, speed=0.5):
        """Blink red LED for specified duration"""
        self.all_off()
        self._blink_animation(RED_LED_PIN, duration, speed)

    def blink_orange(self, duration=3.0, speed=0.5):
        """Blink orange LED for specified duration"""
        self.all_off()
        self._blink_animation(ORANGE_LED_PIN, duration, speed)

    def blink_green(self, duration=3.0, speed=0.5):
        """Blink green LED for specified duration"""
        self.all_off()
        self._blink_animation(GREEN_LED_PIN, duration, speed)

    def cleanup(self):
        """Cleanup GPIO resources"""
        self.stop_animation = True
        if self.animation_thread and self.animation_thread.is_alive():
            self.animation_thread.join()
        self.all_off()
        # Note: We don't call GPIO.cleanup() here as it might be shared
        # with other modules. The main script should handle final cleanup.

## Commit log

2025-11-09 Add files via upload
    wiring diagram
2025-11-10 Enhance README with sample artwork display
    Updated the README to include clickable images for sample artworks.
2025-11-10 Update alt text for sample artwork images
2025-11-13 Change sample artwork image in README
    Updated sample artwork image in README.
